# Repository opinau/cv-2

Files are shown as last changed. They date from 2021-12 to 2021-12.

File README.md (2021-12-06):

# OPINAU-FILLER-CV-2

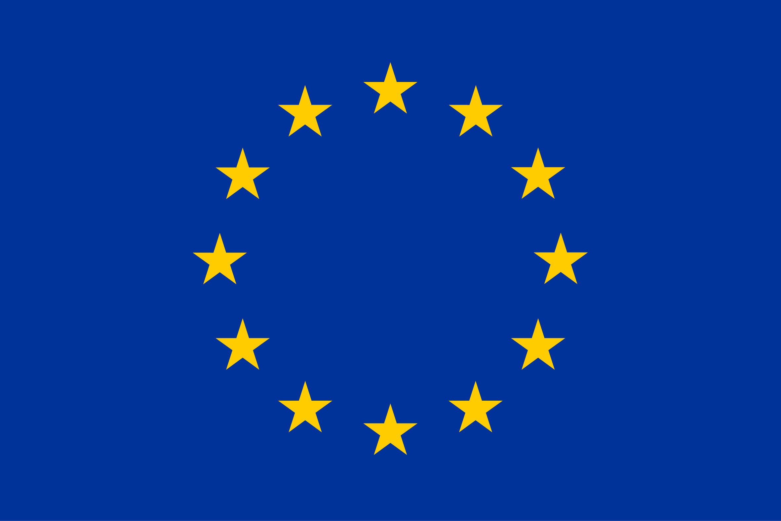
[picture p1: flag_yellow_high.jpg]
EU


Europska unija

Zajedno do fondova EU

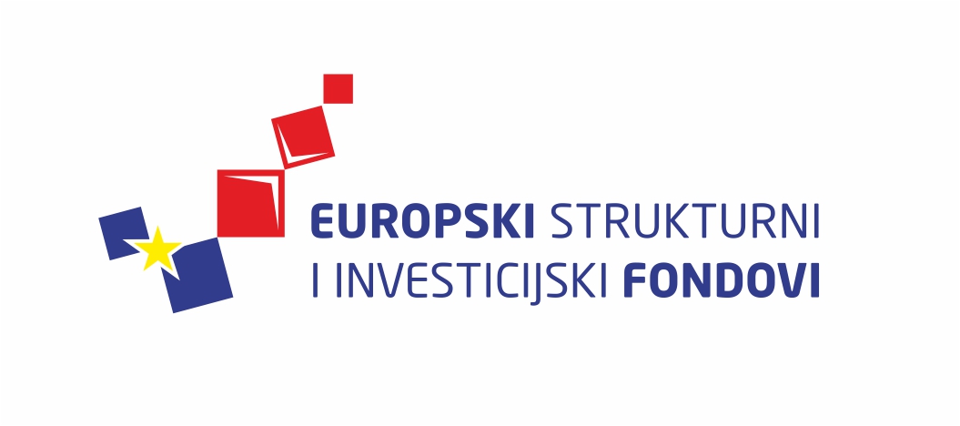
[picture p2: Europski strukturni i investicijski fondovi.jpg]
ESIF (https://strukturnifondovi.hr/)


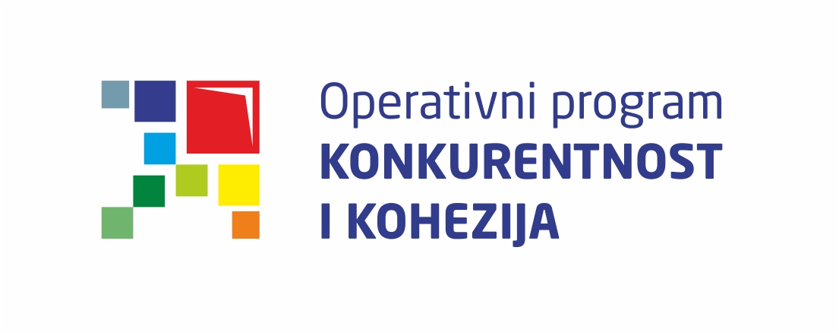
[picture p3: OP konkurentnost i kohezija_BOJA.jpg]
OPKK


Projekt je sufinancirala Europska unija iz Europskog fonda za regionalni razvoj

[**Inovacijski vaučeri za MSP-ove**](https://efondovi.mrrfeu.hr/MISCms/Pozivi/Poziv?id=cfc4e79b-68c5-4ce8-a481-04ee5d76dda2)

Operativni program: **Konkurentnost i Kohezija 2014. - 2020.**

Naziv projekta: **OPINAU-FILLER-CV-2**

OPINAU-FILLER-CV-2 projekt odnosi se na razvoj sklopovlja i popratne programske podrške (unutar Python/C++/ROS okruženja) za prototip sustava za beskontaktno mjerenje razine tekućine u boci prilikom punjenja u open-source punionici piva temeljen na principima računalnog vida sa mogućim odstupanjima od maksimalno 10%.

Partneri na projektu: [**Open Book d.o.o.**](https://www.openbook.hr/) i [**Fakultet elektrotehnike, strojarstva i brodogradnje Sveučilišta u Splitu**](https://www.fesb.unist.hr/)

Ukupna vrijednost projekta: **72.000,00 HRK**

Iznos koji sufinancira EU: **54.000,00 HRK**

Razdoblje provedbe projekta: **09.08.2021. - 03.12.2021.**

Kontakt osoba: **Igor Cota**

---
Repozitorij se sastoji od dva modula:
1. OpenMV modul
2. RaspberryPi modul
---
Prije korištenja pročitajte [dokumentaciju](report/openBookIzvjestaj_ver_4.pdf).

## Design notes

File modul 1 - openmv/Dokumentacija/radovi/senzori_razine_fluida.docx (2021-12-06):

Istraživanje tipova senzora razine fluida

Klasika su Liquid Level Pressure Transmitteri, koji se samo urone u spremnik, to ne igra

Slična stvar je sa ultrazvučnim senzorima i radarskim senzorima, isto ne igraju

Ima jeladn lipi pregled senzora na

https://cecas.clemson.edu/cvel/auto/sensors/fluid-level.html

odnosno

http://www.leveldevilsensors.com/main/electronic-sensors-inc-esi-level-devil-american-made-tank-monitors-and-tank-monitoring-systems/tabk-sensor/

A sada opticki:

Ima na tržištu binarnih senzora razine fluida (zamjena za level switch tj float switch)

https://sstsensing.com/how-our-optical-liquid-level-sensors-work/

Ovoga dosta navode kao optički level nešto..

A sad ide ekipa sa laserima

https://www.lasertech.com/TruSense-S300-Laser-Sensor-Series.aspx

Ovo je ili TOF ili phase whift senzor prilagođen fluidima (ima dodatno raspršenje zrake), relativno visoke razine

Sto se tice cv sustava, tu nalazim vise znanstvenih radova nego pravih komercijalnih sustava

Par linkova:

https://plastrading.com/2017/08/21/how-to-overcome-the-most-common-fill-level-faults-in-full-bottle-containers/

https://heuft.com/en/product/beverage/full-containers/full-container-check-heuft-prime

pitanje je radi li ovo dok se boca puni ili nakon punjenja u liniji?

Koliko se piva pjeni kada se puni?

Ovi imaju nekoliko razlicith sustava za mirenje razina napunjenosti..

Eksplicitno kazu: Not suitable for bottles labelled at the fill level and swing top bottles with a fill level at the bracket area.

https://www.miho.de/en/products/filler-monitoring/filler-monitor-miho-fm-2/

neki fill ic senzor, izgleda dosta jednostavan

http://www.taptone.com/products/fill-level-sensors/fill_ir

ovaj sickov senzor izgleda dosta zanimljiv:

the level is best read from the liquid in the neck of the bottle.

They are mounted on the level probe directly to facilitate optimum detection.

https://www.sick.com/us/en/primary-packaging/filler/measuring-the-level-of-the-bottle/c/p514290

stranica na njemackom, dosta slica ideji o kojoj smo pricali vezano uz laser liniju (planarno) ANWENDUNGEN DER OPTISCHE FÜLLSTANDSKONTROLLE

https://www.bbull.com/binternet/deutsch/sites_d/pro_details_d/fuellstandskontrolle_d/fuellstandskontrolle_d.htm

neki clanak vezano uz koriostenje kamera (cmos / ccd senzor)

https://graphene.limited/deep-dive-into-technology-2/full-container-inspection/fill-level-inspection/optic-with-camera-2/index.html

zanimljivo, ali zahtjeva da nema labelu i da je skorz tranparentan..

https://graphene.limited/deep-dive-into-technology-2/full-container-inspection/fill-level-inspection/laser-fill-level-inspection-2.html

Ukratko, možemo ici u 2 smjera,

- Kamera i neka trigonometrijska shema (tu svatsa moze smetat snimanju, ne virujen da ce imat dobar response time, kakvih 5-6 ocitanja po s)
- Optički ic senzor koji se montira na tip punilice, ograničen u mjerenu razine ali iznimno brz i jednostavan. Moze se ocekivat i preko 100 ocitanja po s.

Ima nekoliko radova koji se baziraju na cisto mv sustavima,openmv + phyton + edge detetction (radove sam skinio)

Triba provjerit kako se ponasa laser line na boci

Lase point lasnisran vertikalno kroz bocu

Kako se vidi zapjenjeni dio

Kamera + ic Led, 'c filter za kameru, tekucine u ic spektru se dosta reflektiraju..

Neke od ideja…

Nekakvi pocetni plan opreme:

RPI 4GB

Kamera no ic cut + ic pass filter

Opencv kamere sa ddr ram, mozda i dodatna noic cut kamera

Proxyimity senzori

Laseri mali + fotodiode

Laser tocka

Laser linija

Difuzerski materijali..

O ovme jos triba raspravit

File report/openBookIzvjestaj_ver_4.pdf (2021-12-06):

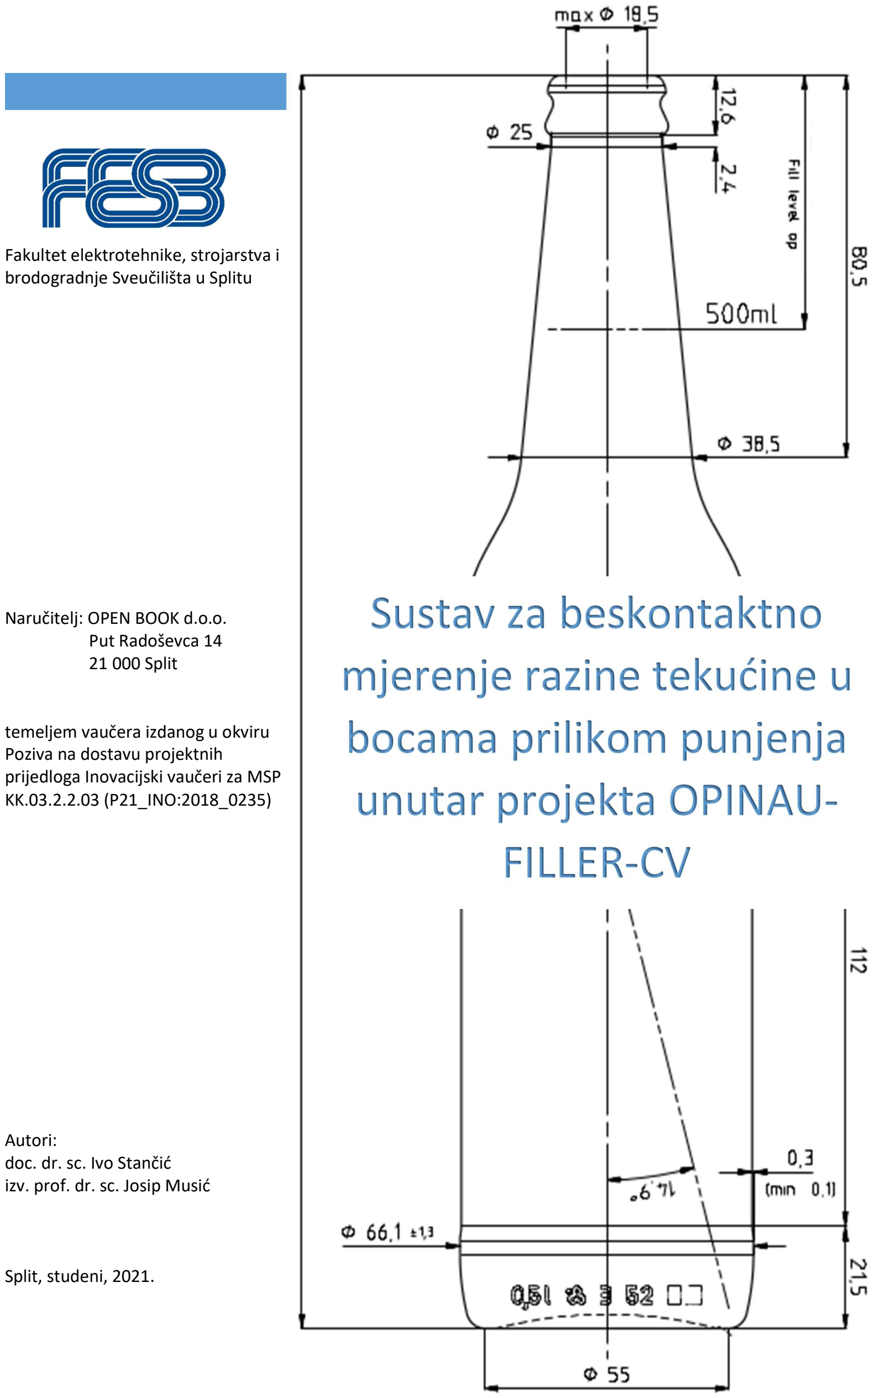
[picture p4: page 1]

1

OPINAU-FILLER-CV

Fakultet elektrotehnike, strojarstva i brodogradnje Sveučilišta u Splitu

Naručitelj: OPEN BOOK d.o.o.
Put Radoševca 14
21 000 Split

temeljem vaučera izdanog u okviru Poziva na dostavu projektnih prijedloga Inovacijski vaučeri za MSP KK.03.2.2.03 (P21_INO:2018_0235)

Autori:
doc. dr. sc. Ivo Stančić
izv. prof. dr. sc. Josip Musić

Split, studeni, 2021.

# Sustav za beskontaktno mjerenje razine tekućine u bocama prilikom punjenja unutar projekta OPINAU-FILLER-CV

## SADRŽAJ

3

## 1. MOTIVACIJA I CILJ

Naručitelj sustava, tvrtka OPEN BOOK d.o.o., je u procesu izrade open-source (sklopovski i programski) tipa punionice za male pivovare odnosno tzv. craft piva. Glavna odlika takvih pivovara odnosno piva je mala serija proizvodnje odnosno izrada od strane pojedinaca (entuzijasta) i manjih poduzeća. Stoga je jedna od glavnih odlika koje razvijeni sustav treba imati cjenovna pristupačnost kao i jednostavna dostupnost svih komponenti od kojih se sustav sastoji, pri čemu sustav ne mora biti u mogućnosti obraditi veliki broj boca kao velike pivovare. Dodatno, potrebno je da je sustav lako za održavati te zamijeniti neispravne komponente, pa čak i da vlasnik/korisnik može intervenirati u programski kod i/ili dodati dodatno sklopovlje (npr. senzoriku). Tragom navedenoga tvrtka OPEN BOOK je izradila prototip punionice (Slika 1) koja sa sastoji od pokretne trake, dijela za lijepljenje naljepnica na boce, punilice pivom i čepilice, a dijelovi za koje su dostupni kao STL datoteke za 3D printanje, odnosno ključne elektroničke komponente putem platformi za trgovinu kao što su e-Bay odnosno AliExpress.

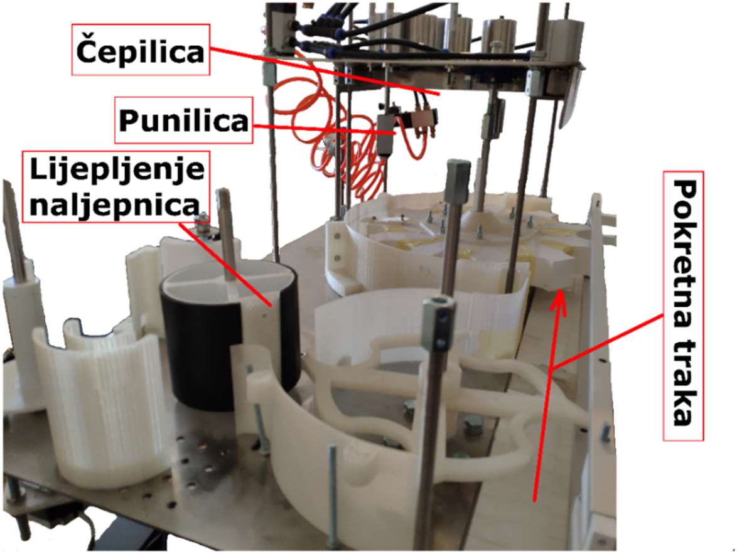
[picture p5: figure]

Slika 1 – Radni prototip OPINAU-FILLER sa naznačenim osnovnim dijelovima (strelica prikazuje smjer kretanja boce) – starija verzija prototpia

Glavni pokretači (Nema 23 bipolarni koračajni motor¹
) prototipa punionice su
dizajnirani i integrirani u sustav, kao i senzorika za praćenje njihovoga rada i trenutno stanja (položaja) boca unutar sustava. Međutim, dio kojemu nedostaje senzorika a kako bi se mogla zatvoriti povratna upravljačka veza je sama punilica. Naime sustav u trenutnoj konfiguraciji ne posjeduje informaciju o stvarnom stanju razine piva tijekom punjenja, već ventil za punjenje drži otvorenim unaprijed određeno vrijeme. Prilikom punjenja, a kako bi se smanjilo pjenjenje, boca sa pod pritiskom prvo napuni ugljičnim dioksidom (korak pripreme) a zatim kreće samo punjenje pivom. Budući da ugljični dioksid dolazi iz spremnika pod pritiskom, a čiji pritisak

1 https://www.omc-stepperonline.com/nema-23-bipolar-1-8deg-1-26nm-178-4oz-in-2-8a-2-5v-57x57x56mm-4-wires.html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

4

opada kako se boca dioksida prazni, to se pritisak u boci piva prilikom punjenja također mijenja. Ovo pak za posljedicu može imati da vrijeme punjenja (u otvorenoj petlji) koje se postavi kada je boca dioksida puna više nije dovoljno dobro kako se boca prazni. Iako su tolerancije prilikom punjenja relativno velike (10% prema zahtjevu naručitelja), poželjno je da punjenje bude što bliže deklariranoj vrijednosti, te da se u slučaju neželjenih efekata (prepunjena boce, preveliko pjenjenje i slično) proces može ili zaustaviti ili obavijestiti operatera o nastaloj grešci.
Prije početka razvoja traženog modula za detekciju razine tekućine u boci prilikom punjenja, napravljen je kratki pregled dostupnih znanstvenih i komercijalnih sustava. Predstavljanje potpunog pregleda izlazi izvan okvira ove studije, ali moguće je konstatirati da se dostupni senzori mogu grubo podijeliti u dvije skupine: kontaktni i beskontaktni. Daljnja podjela je moguća s obzirom na princip rada²
: mehanički, magnetski, elektrostatički, ultrazvučni, optički i slično. Moguća je i kombinacija više senzorskih modaliteta u jednu
jedinicu | kao | npr. | u | komercijalnom | sustavu | Heuft | Prime
(https://heuft.com/en/product/beverage/full-containers/full-container-check-heuft-prime). Potrebno je također primijetiti da se razina tekućine može mjeriti na dva mjesta: prilikom samog punjenja (što je izazovniji problem zbog prisustva mlaza za punjenje i eventualnih dodatnih dijelova punilice a u svrhu uključenja u regulacijsku petlju – to je problem kojim se bavi ova studija) ili nakon punjenja samo za kontrolu razine (ova studija samo predlaže rješenje za ovaj slučaj ali ga detaljnije ne razmatra i testira)..
Zbog sanitarnih razloga i zahtijeva koje oni nameću poželjno je da senzor za mjerenje razine tekućine u boci prilikom punjenja bude beskontaktan. Stoga su metode strojnog vida prepoznate kao dobri kandidati koji osim što zadovoljavaju zdravstvene kriterije (beskontaktnost) se vrlo dobro uklapaju u paradigmu otvorenog pristupa istaknutu u uvodu (npr. lako ih je mijenjati i nadograditi). Pri tome su postavljeni slijedeći konstrukcijski zahtjevi: 1.) potrebno je koristiti lako dobavljive i cjenovno pristupačne komponente, 2.) sklopovlje mora po svojim dimenzijama mora biti prikladno za integraciju u razvijeni prototip punionice, 3.) sustav treba raditi u realnom vremenu s latencijom ne većom od 200 ms što odgovara brizni ne manjom od 5 sličica u sekundi, 4.) programska podrška treba na svome izlazu davati kontinuiranu vrijednost (trenutno stanje razine) kao i diskretnu vrijednost (da li je dosegnuta željena razina punjenja), 5.) izlaz iz programske podrške treba biti pogodan za kasnije spajanje s ROS-om (eng. Robotic Operating System³
), 6.) sustav treba biti otporan na promjene osvjetljenja u radnoj okolini, i 7.) sustav treba biti lak za rukovanje (posebno kalibracijska faza – ukoliko je potrebna).
Tijekom ove studije inicijalno je testirano više pristupa upotrebom različitih modaliteta (sklopovlja) mjerenja, ali su naposlijetku dva odabrana kao obećavajuća te su stoga detaljnije predstavljena u ovome Izvještaju (primjer jednoga sustava je na Slici 2), i za njih su razvijeni prototipovi modula. Navedeni su osnovni sastavni dijelovi kako bi se mogli jednostavno reproducirati (open-source filozofija), kao i cjeloviti kod koji se planira učiniti javno dostupnim

2 http://www.leveldevilsensors.com/main/electronic-sensors-inc-esi-level-devil-american-made-tank-monitors-and-tank-monitoring-systems/tabk-sensor/

### 3 https://www.ros.org/

5

(pod odgovarajućim licencama) putem GitHub platforme⁴
(opet, u skladu s open-source filozofijom). Potrebno je napomenuti da su svi moduli detaljno testirani u laboratorijskim uvjetima sa ciljanim tipovima boca piva (kojima su i prilagođeni) dok u praktičnoj eksploataciji se mogu javiti neke dodatne neplanirane situacije koje će se trebati naknadno adresirati. Kako bi se minimizirao ovaj efekt jedan od razvijenih prototipova (Modula 1) je u dogovoru s naručiteljem i kratko testiran u relni(ji)m uvjetima prave punionice (ali ne i prilikom stvarnoga punjenja piva). Također, razvoj sustava je prilagođen određenom tipu i udaljenosti pivske boce, ali je kroz (jednostavni) postupak kalibracije (putem ugrađenog mini LCD ekrana) ostavljena mogućnost prilagodbe istih, te posljedične programske prilagodbe odgovarajućih programskih/mjernih parametara. Na taj način je modul postao fleksibilniji i moguće ga je koristiti u više različitih konfiguracija i više različitih namjena. Svi kodovi su pisani u Python programskom jeziku, tako da i korisnici sa manje iskustva mogu po želji prilagođavati funkcionalnost modula.
Naposljetku je potrebno još jednom istaknuti i činjenicu da je tijekom razvoja predloženih sustava testirano više različitih kamera, senzora i mikrokontrolera (u vidu brzine i pouzdanosti rada kao i jednostavnosti upotrebe i nadogradnje), te su predstavljene komponente one koju su naposljetku odabrane a koje ispunjavaju tražene kriterije naručitelja. Za potrebe modula je dizajnirana i izrađena posebna tiskana pločica kao i dizajnirano više mehaničkih dijelova od aluminijskih profila.

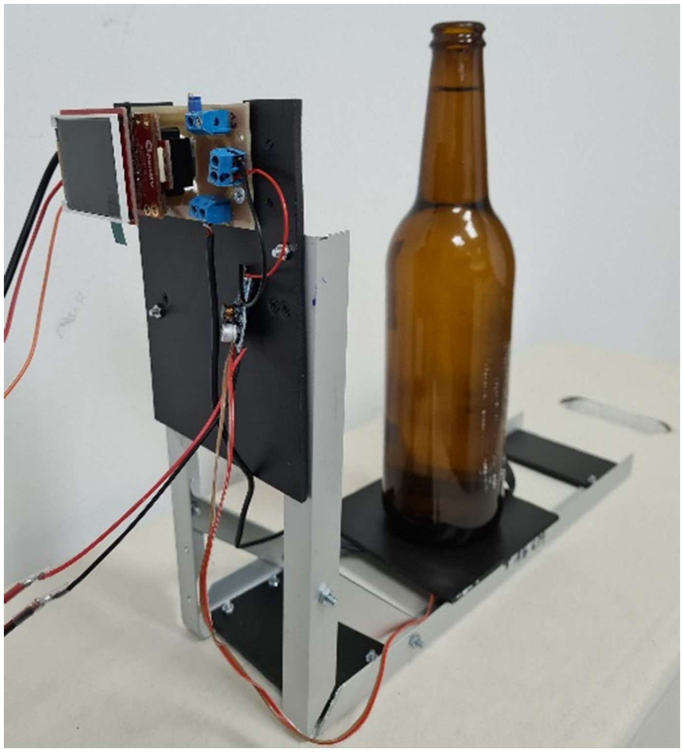
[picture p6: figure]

Slika 2 – Primjer jednog modula razvijenog prilikom izrade studije

Prilikom razvoja sustava za praćenje je testirano nekoliko kombinacija najpopularnijih kamera i mikro kontrolera koji se koriste u MV-u (eng. Machine Vision). Odluka da se u konačnici ne koristi niti jedan specifični mikrokontroler (ugradbeno računalo) već stand-alone kamera je bilo motivirano činjenicom da sustav bude prijenosan i da se može jednostavnije integrirati u postojeću upravljačku logiku. Dodatno, ovakva odluka doprinosi jednostavnosti izgradnje i održavanja sustava, Zbog potpunosti razmatra neki od predloženih sustava su testirani i sa Raspberry Pi 4B+ ugradbenim računalom. Jednostavna usporedba nazivnih

### 4 https://github.com/

6

vrijednosti je na strani RPi platforme budući da testovi pokazuju znatnu razliku između OpenMV H7 plus kamere (ARM Cortex-M7) koja radi na taktu 480 MHz i Raspberry Pi 4B (ARM.Cortex A72) na taktu 1.5GHz (Core Mark Performance 2400 u odnosu na 48,626)⁵ 6 .
Međutim OpenMV H7 plus je dizajniran za primjene strojnog vida, pa kao takav ima neke prednosti kao što su: brza sabirnica (3.84 GB/s), manja potrošnja energije, manje dimenzije i integrirana kamera i mikrokontroler, izravno programiranje i slično. Upravo iz navedenih razloga je isti bio prvi izbor u razvoju predloženog sustava.
Primjer svog testiranog sklopovlje je dan u Tablici 1 kako bi čitatelj dobio bolji osjećaj za performanse drugog sklopovlja, te stoga nisu namijenjeni za direktnu usporedbu s konačnim sustavom. Također, smatramo da bi uključivanje potpunih preliminarnih rezultata u ovu studiju nepotrebno pomaklo fokus sa predloženog sustava i njegovih karakteristika, te stoga oni i nisu uključeni (već samo njihov sažetak kako slijedi).
Inicijalna ideja sustava za detekciju razine tekućine u boci se temeljila na primjeni linijskog lasera i detekcija efekta refrakcije/loma svjetlosti (primjer detekcije na Slici 3). Međutim, testiranja su pokazala da zbog specifičnosti upotrjebljenih boca (nesavršenog oblika) i radnog okruženja željeni efekti nisu dovoljno izraženi i stabilni da bi bili primjenjivi, te se stoga odustalo od navedene ideje. Npr. primijetilo se da jako mali pomaci boce (tek nekoliko mm) mogu rezultirati pomakom zrake, što se može prepoznati kao lažno napunjenost boce.

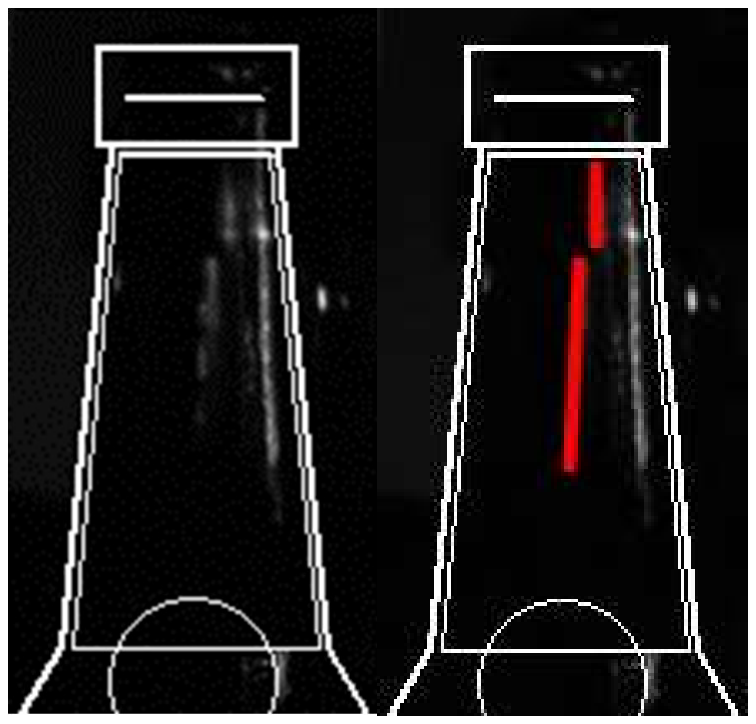
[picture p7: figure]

Slika 3 – Primjer loma laserske linije kod detekcije razine tekućine
Na slične probleme se naišlo kod pokušaja primjene IR senzora udaljenosti: zbog boce i zaštita koje ima nije bilo moguće dobiti smisleno i stabilno rješenje. Stoga se pristupilo pronalaženju alternativnih principa rada, a koji će biti predstavljeni u slijedećem poglavlju. Dodatna ideja koja se testirala ali koja nije pokazala zadovoljavajuće rezultate (pa se stoga odustalo od njezina daljnjeg razvoja i testiranja) se temeljila na svojstvu apsorpcija svjetlosti boce i tekućine. Kako se radi o jako maloj količine relativno prozirne tekućine, smanjenje intenziteta svjetlosti zbog apsorpcije u tekućini je minimalno i u ovom slučaju nije davalo dovoljno kvalitetne rezultate (primjer na Slici 4). Na slici je prikazan idealan slučaj kada se linija jako dobro može razaznati ali u realnim situacijama zbog male razlike intenziteta

### 5 https://www.eembc.org/viewer/?benchmark_seq=13417 6 https://openmv.io/products/openmv-cam-h7-plus

7

„linije“ tekućine i ostatka boce razlika je minimalna i podložna utjecaju smetni (npr. okolnog osvjetljenja).

Slika 4 – Primjer detekcije razine tekućine temeljem svojstva

Tablica 1 – Usporedba osnovnih karakteristika testiranog sklopovlja tijekom studije
Sklopovlje | Rezolucija/ udaljenost | Podržane platforme | Ostale (bitne) karakteristike
Arducam OV9281 1MP kamera | 1280x800 (1MP) | Raspberry Pi 4, Pi 3/3B+/3A+, CM3/3+, Pi Zero, Arduino | Monokromatski globalni shutter. Senzor ¼ incha. Ugrađen 650nm IR cut-off filter (samo vidljiva svjetlost). Maksimalna brzina 120 fps. Veličina 40x40 mm.
Arducam Stereoscopic Camera kit OV9281 | 1280x800 (1MP) | Raspberry Pi 3B/3B+/4B and Jetson Nano/NX | Dvije OV9281 !MP kamere sa sinkroniziranim globalnim shutterom. RAW8/RAW10/RAW12 izlazni format. Bez IR filtera (osjetljivo na IR). MIPI serijsko sučelje. Distorzija <1%. FOV 70 stupnjeva (H).
OpenMV H7 plus | 592x1944 (5MP) | Neovisno o računalnoj platformi (stand alone ili serijska veza sa drugim uređajem) | STM32H743II ARM Cortex M7 procesor sa 480 MHz i 32MB SDRAM + 1MB RAM + 32 MB vanjskog flasha + 2 MB unutarnjeg flasha.OV5640 optički senzor. Može vrtiti custom algoritme na svome procesoru s brzinama do 50 fps.
Pololu 38kHz IR senzor blizine | 60 cm | Analogno sučelje – sve ploče koje imaju pinove koji mogu čitati analogne signale | Baziran na Vishay’s TSSP77038 modulacijskim IR prijemnicima. Digitalni senzor sa prilagodljivijom (trimmer) referentonm udaljenošću.
Zeleni laser snage 25 mW | 3 m (tipično) | NA | Prilagodljivi fokus. Kut 60 stupnjeva. Akrilni kolimator. Napajanje 12 – 25 VDC. Valna duljina 515-520 nm. Klasa 1/2.

8

## 2. MODUL ZA DETEKCIJU RAZINE TEKUĆINE PRILIKOM PUNJENJA – Modul 1

Prototip (laboratorijskog) sustava za detekciju razine tekućine u boci je prikazan na Slici 5 (s označenim glavnim dijelovima), a njegovo planirano mjesto na proizvodnoj liniji (Slika 1) je u punilici. Potrebno je primijetiti da prototip sadrži i neke konstrukcijske i nosive dijelove (aluminijski profili) koji neće nužno biti dio prototipa na proizvodnoj liniji budući da će se sustav postavljati na već postojeću konstrukciju na za to prikladan način. Pri tome će osim dodavanja komponenti, zbog prirode razvijenog sustava biti potrebno i prilagoditi postojeće komponente (podloga na kojoj se boca nalazi) a kako bi se mogle ugraditi ključne komponente (LED). Slika 5 sadrži detaljan uvid u sve komponente laboratorijskog sustava.

Slika 5 – Prototip modula za detekciju razine tekućine u boci s označenim osnovnim dijelovima iz nekoliko kuta gledanja

9

Iz donjeg dijela Slike 5 je vidljivo da da predloženi sustav ne detektira razinu tekućine na cijeloj visini boce, već samo na završnom dijelu (vrhu) gdje je to kod punjenja i najbitnije. Važna pretpostavka je da u trenutku punjenja boca još uvijek nema nikakvu naljepnicu na svome grlu. Naime na ovaj način, fokusiranjem područja, se postigla bolja točnost i pouzdanost mjerenja koja kod širega kuta ne bi bila moguća. Primjer vidnog polja OpenMV H7 plus kamere sa naznačenom minimalnom (donja linija) i maksimalnom (gornja linija) razinom tekućine za mjerenje dan je na Slici 6 (udaljenost kamere od boce je bila približno 16 cm). U konkretnom primjeru za naznačene linije radilo se o napunjenosti boce između 470 i 520 ml (pri čemu su očekivane manje varijacije zbog tolerancija kod proizvodnje boca).

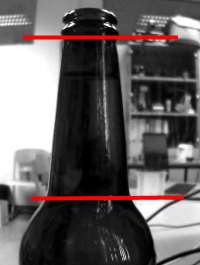
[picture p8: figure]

Slika 6 – Boca iz vidnog polja kamere s oznakama minimalne i maksimalne razine tekućine koje može izmjeriti

Metode mjerenja razine fluida u transparentnoj ili polu-transparentnoj posudi (boci) u predloženom sustavu se temelje na ključnom svojstvu materijala: reflektivnosti. Pretpostavka je da jaki izvor svjetlosti osvjetljava bocu (od dolje) u jako kratkim vremenskim intervalima (nekoliko ms), i svjetlost se širi od dna boce prema vrhu, pri čemu se rasprostranjuje cijelom bocom (ovo je iznimno važno, ne radi se o usmjerenom svjetlosti već o izvoru svjetlosti sa velikim kutom djelovanja). Svjetlost se reflektira kada prelazi između različitih medija (Snellusov zakon⁷
), što uključuje prelazak iz fluida na staklo ali i sa fluida na zrak. Dio svjetlosti koji se reflektira prilikom prelaska iz fluida u zrak upada u leću kamera, i kamera ga vidi kao područje jačeg intenziteta svjetlosti. Kamera snima dvije slike u kratkim vremenskim razmacima, pri čemu je prva slika osvjetljena snažnim LED izvorom, dok je druga slika u normalnim uvjetima (bez dodatnog izvora svjetlosti). Jednostavnom operacijom oduzimanja se mogu izdvojit razlike među tim slikama. Ovaj efekt i njegovi rezultati su prikazani na Slici 7.

### 7 https://www.enciklopedija.hr/natuknica.aspx?ID=52225

10

Slika 7 – Operacije nad slikama snimljenim u dva uzastopna trenutka (sa i bez LED osvjetljenja)
Osim refleksije od prelaska svjetlosti iz fluida u zrak, na slici 7 (desno) se može detektirati i refleksija koja je posljedica prelaska svjetlosti iz fluid u staklo na samom početku grla (donja oznaka). Navedemo je detaljnije označeno i prikazano na Slici 8.

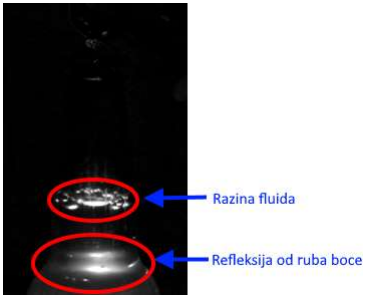
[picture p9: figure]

Slika 8 – Refleksije zbog efekata na boci i razine tekućine u boci

Premda je ova refleksija manje-više ujednačenog oblika u istoj boci, zbog različitih oblika boca (velikih tolerancija tokom izrade) mogu se promotriti različiti oblici refleksije. Zbog ovoga je dio početka grla boce jednostavno izbačen iz analize, te se promatraju refleksije samo na ostatku grla boce predefinirane veličine, a što je predstavljeno maskom vidljivom na Slici 9.

11

Slika 9 – Maska za definiranje mjernog područja i minimizaciju utjecaja neželjenih artefakata

Ovdje je potrebno istaknuti da se prilikom razvoja sustava testiralo više različitih izvora svjetlosti (primjeri rezultata su prikazani na Slici 10), ali se najboljim izvorom pokazala obična bijela LED snage minimalno 1W (koja se inače koristi za automobilske farove – smatramo da odabir navedene komponente ima značajnu prednost što već sadrži regulator koji se brine za ispravno napajanje naponom i strujom LED-a). Isto tako testirano je i više leća sa filterima: IC cut, IC pass i bez ikakvog IC filtera na leći (Slika 11).

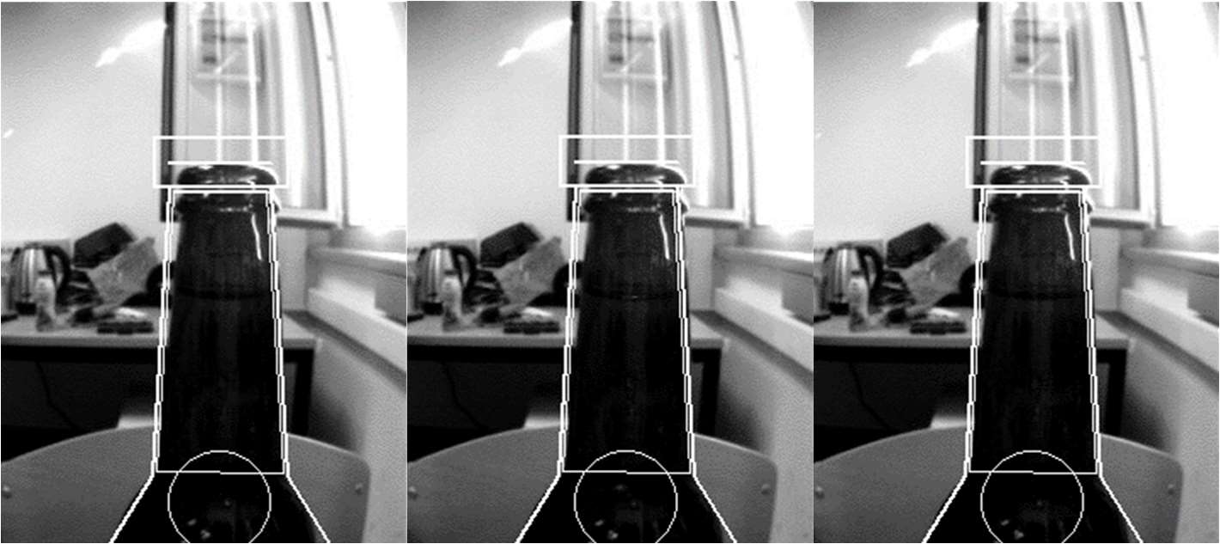
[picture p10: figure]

IR 1W | crveni LED 10mW | UV 395nm

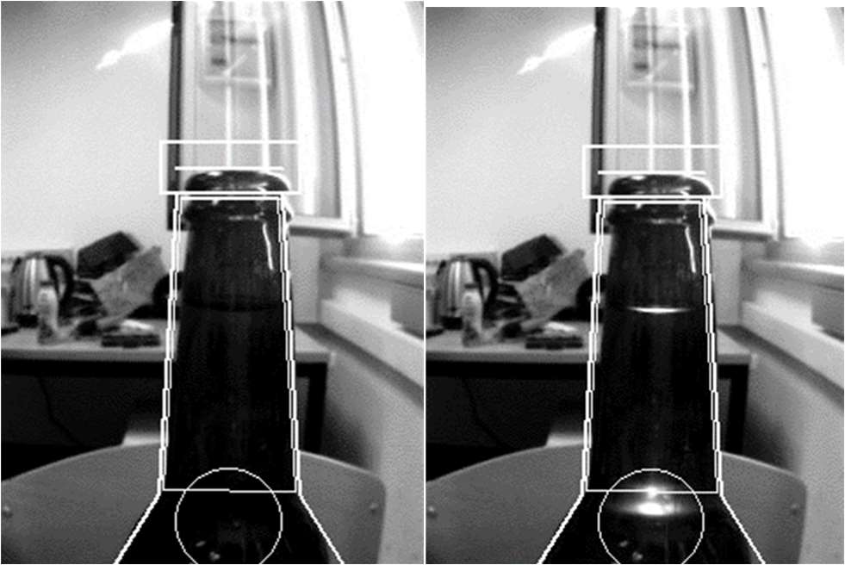
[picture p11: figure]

uv 420nm | bijeli LED 1W

Slika 10 – Primjeri testiranja različitih vrsta izvora svjetlosti ispod pivske boce

12

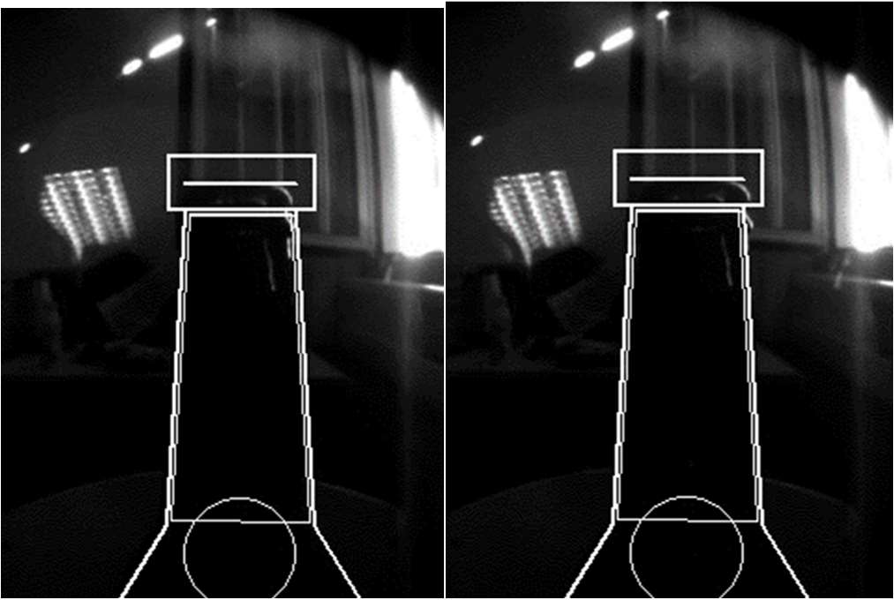
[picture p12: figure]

IR pass, izgašeno | IR pass, IR 1W

Slika 11 – Primjeri testiranja različitih vrsta filtera

Tijekom testiranja sustava zamijećeno je da oblik refleksije koji kamera može zabilježiti se može svrstati u 3 različite kategorije, kao što je i prikazano na Slici 12, a što se onda može dodatno iskoristiti za klasifikaciju događaja u boci/punilici (pri budućem razvoju).

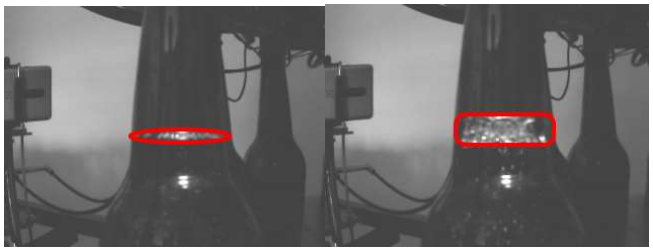
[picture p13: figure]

Tip 1 | Tip 2

Tip 3

Slika 12 – Primjeri različitih jedinstvenih uzoraka zamijećenih tijekom testiranja sustava

13

Različiti su oblici primijećeni kada fluid miruje, i kada se boca puni fluidom, pa je i sam algoritam sustava strojnog vida prilagođen da može detektirati bilo koji od potencijalnih oblike. Pa tako Tip 1 na Slici 12 predstavlja mirnu razinu tekućine bez (ili s vrlo malo) pjene, dok Tip 2 predstavlja razinu koja se još nije ustalila budući da ima značajan udio pjene. Tip 3 je karakterističan za sam proces punjenja, kada tekućina koja dolazi iz punilice upada u tekućinu u bocu ispod razine trenutnog punjenja a što je vidljivo kao niz manjih površina ispod najviše detektirane razine (koja predstavlja razinu tekućine).
Konačna inačica sustava implementirana unutar mikrokontrolera OpenMV H7 plus kamere doseže brzinu rada od oko 7 parova sličica u sekundi (fps; jedna potpuna obrada traje oko 150 ms), što bi trebalo biti dovoljno za upravljanje punjenja boce koje traje predvidivo 10-30 s. Uzevši u obzir navedeno vrijeme punjenja (30 s), kao i ciljani volumen boce (500 ml) proizlazi prosječna brzina punjenja od oko 16.5 ml/s. Ukoliko se uzme brzina snimanja od 7 fps-a, jednostavnim računom se dobije da je teoretska rezolucija sustava (tj. minimalna razlika promjene volumena između dva snimljena okvira) oko 2.3 ml.
Premda je sustav detekcije razine na kojoj se nalazi „refleksija“ (tj. razina tekućine) iznimno precizan, zbog nemogućnosti točnog razlikovanja radi li se samo o fluidu ili postojanju male količine pjene, ovaj sustav je točan u razini ~ 2-5 ml. Radi usporedbe veličina na slici i u stvarnosti napominjemo da na sredini grla boce razlika od 20 piksela odgovara razlici volumne fluida od oko 5 ml. Pri tome sustav radi na rezoluciji od 320 x 240 piksela, dok je radno područje sustava (maska sa slike 9) visine oko 150 piksela, i odgovara razini fluida u prosječnoj boci od 470 do 520 ml.
Tijekom razvoja sustava isti princip rada testiran je s drugačijim sklopovljem odnosno sa ArduCam OV9281 1Mpix (NoIR) kamerom u kombinaciji s Raspberry P 4 Model B (Slika 13). Ovakva kombinacija se pokazala sposobnom ostvariti znatno veće brzine rada od 20 fps-a, međutim zbog jednostavnosti samog senzora (sustava) za krajnju realizaciju se predlaže pristup sa OpenMV kamerom (koji ima prednost i da prilikom ponovnog paljenja se znatno brže podiže od RPi računala). Izgled mjernog sustava za ovakve postavke je prikazan na Slici 14.

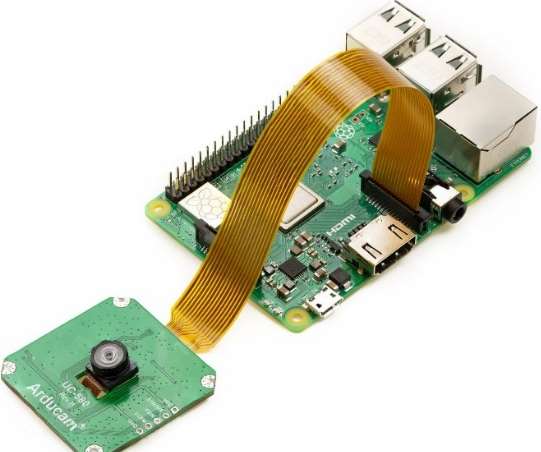
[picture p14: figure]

Slika 13 – Način spajanja Arducam OV9281 1Mpix kamera sa RPi 4B računalom

14

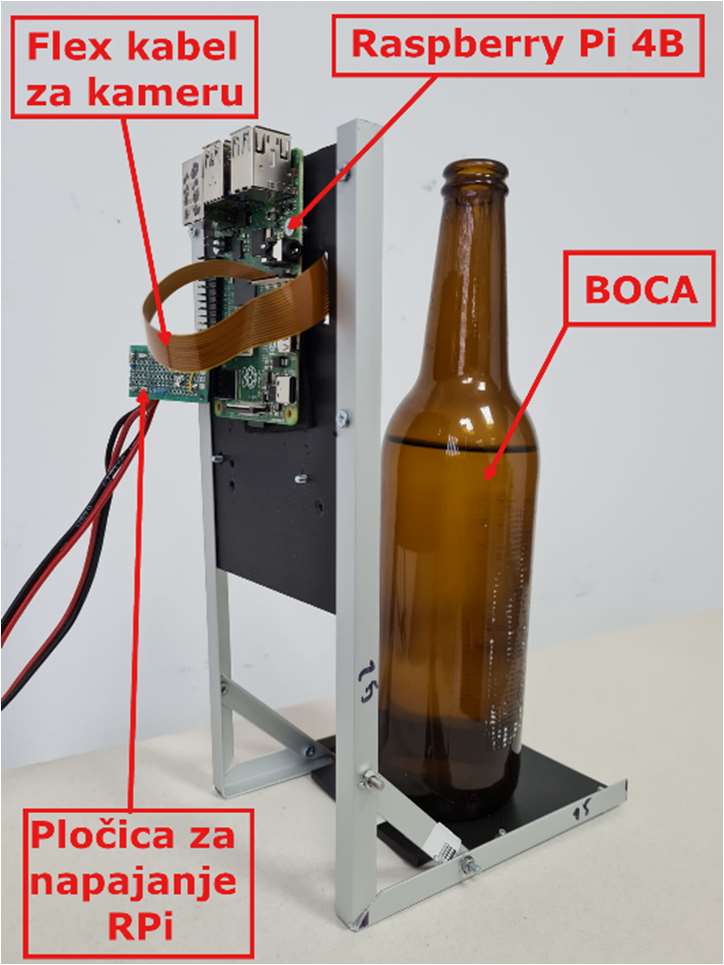
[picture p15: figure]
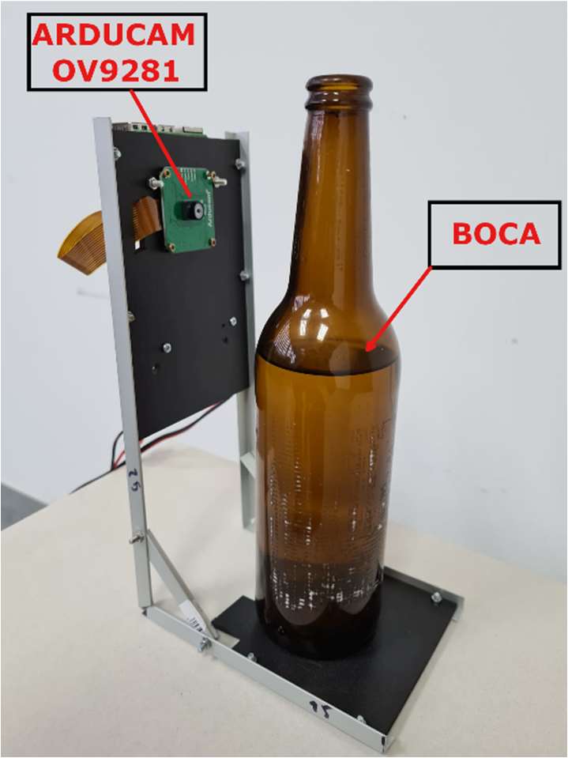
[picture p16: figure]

Slika 14 – Način spajanja Arducam OV9281 1Mpix kamera sa RPi 4B računalom

Pri radu s OpenMV H7 plus kamerom bilo ju je potrebno unutar Python programskog okruženja postaviti na njezinom mikrokontoleru njezine postavke na slijedeći način (a kako bi se ostvarili/reproducirali ovdje prikazani rezultati):

sensor.set_pixformat(sensor.GRAYSCALE) # set camera format to grayscale (color not important in this example)

sensor.set_framesize(sensor.QVGA) # set camera resolution to QVGA 320 x 240

sensor.set_auto_exposure(False, exposure_us=user_exposure_time) # set exposure time, user changable (user_exposure_time variable)

sensor.set_auto_gain(False,gain_db=22) #set camera gain, keep it as this value is optimised for given light source and exposure time

sensor.set_brightness(3) #set camera brightness , range -3 to +3

sensor.set_contrast(3) #set camera contrast , range -3 to +3

Naravno, parametre je moguće naknadno mijenjati s obzirom na tražena svojstva i svojstva okoline gdje se senzor postavlja. Dodatno ključno svojstvo koje se postavlja je:

sensor.set_framebuffers(1)

koji omogućava kameri da snima samo jednu sliku u framebuffer, tako da kamera mikrokontroleru šalje samo najsvježiju sliku na obradu. Što se tiče samog postupka dobivanja

15

razlike slika kada je LED upaljen i ugašen (Slika 7), odnosno tzv. frame differencinga, on se može jednostavno implementirati putem slijedećih naredbi:

pin_LED.value(True) #turn on main LED

time.sleep_ms(5) #sleep for 5ms (allow LED to reach full brightness)

img = sensor.snapshot() #take first image (led is on)
time.sleep_ms(2) | # wait for a few ms
extra_fb.replace(sensor.snapshot()) | #put first image in to
additional frame buffer
pin_LED.value(False) | #turn off main LED
time.sleep_ms(5)

img = sensor.snapshot() #take second image (led is off)
time.sleep_ms(2) | # wait for a few ms
img.difference(extra_fb) #simple frame differencing, first and second image

Važan prvi korak pri instaliranju sustava (koji se radi samo jednom i eventualno dodatno ako dođe to pomicanja nosivih komponenti/dijelova) je kalibracija sustava. Zadatak kalibracije je namjestiti kameru i nosivu konstrukciju na način da se boca prilikom punjenja nalazi u dijelu slike u kojem je očekuje (i s kojim radi i za koji ima masku) a kako bi se grlo boce (odnosno gornji dio boce) moglo pouzdano i točno izdvojiti. Kako bi se olakšao ovaj postupak u uvjetima realne primjene, u sustav je ugrađen mali LCD ekran koji se pali uklanjanjem kratkospojnika sa slike 5. U tome trenutku pali se spomenuti LCD ekran te se na njemu prikazuje slika sa OpenMV H7 plus kamere i template boce koji služi za namještanje (vidljiv na Slici 15).

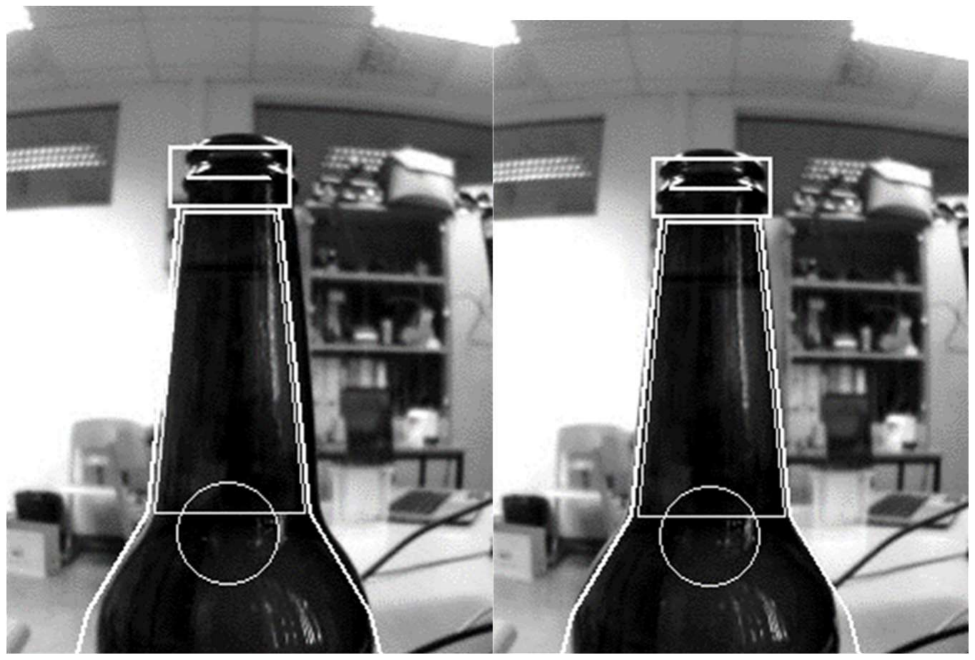
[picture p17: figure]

Slika 15 – Način spajanja Arducam OV9281 1Mpix kamera sa RPi 4B računalom

16

Korisnik zatim treba bilo pomicanjem položaja boce koja se puni (što je teže za očekivati) ili konstrukcije koja nosi kameru, namjestiti bocu da što bolje odgovara templateu (pri čemu je template izrađen za vrstu boce koja se koristi u punionici). Na lijevom dijelu slike 15 se vidi da poklapanje boce i templatea nije idealno (boca je previše desno), dok na desnom dijelu slike poklapanje je idealno. Jednom kada se postigne zadovoljavajuće preklapanje i konstrukcijski dijelovi učvrste u novom položaju, vrati se kratkospojnik koji uzrokuje gašenje ekrana (na njemu je samo logo tvrtke OPEN BOOK d.o.o.). Time je sustav spreman za rad (sa deklariranom točnošću) te LED počinju bljeskat (jednom kada dobiju naredbu za početak sa udaljenog centralnog računala). Ukoliko je potrebno postupak kalibracije je moguće ponoviti skidanjem kratkospojnika.
Paljenje i gašenje LED izvora bijele svjetlosti je ostvareno korištenjem MOSFET-a IRFZ44N. Kako bi se ovaj MOSFET i druge komponente (npr. kratkospojnik) mogli jednostavno integrirati sa OpenMV H7 plus kamerom i njezinom pločicom u programskom okruženju KiCad je izrađena prilagođena tiskana pločica koja je zatim i proizvedena. Izgled pločice unutar KiCad programa je vidljiva na Slici 16.

Slika 16 – Izgled KiCad sučelja sa dizajniranom prilagođenom tiskanom pločicom

U trenutnoj implementaciji razvijeni sustav nije integriran unutra ROS čvora (kao krajnjoj ciljanoj arhitekturi razvijenog sustava), ali je kao generalna priprema (ne samo za ROS već i za druge moguće arhitekture) implementirano izvještavanje o stanju punjenja boce putem standardiziranih poruka i USART komunikacijskog sučelja. U slučaju da se radi o ROS arhitekturi ovakve poruke bi se mogle slati na npr. Arduino Nano mikrokontroler koji bi ih primao i na sebi imao pokrenut ROS čvor koji bi ih zatim objavljivao unutar ROS arhitekture. Slanje preko USART komunikacijskog sučelja na OpenMV H7 plus mikrokontroleru je implementirano sa naredbama (koje se naravno po potrebi mogu mijenjati):

uart = UART(4, 9600) #UART pin 4, 9600 baudrate

uart.write(message+"\n")

17

Objekt message koji se šalje odnosno koji služi za izvještavanje sadrži slijedeća podatkovna polja: message = <a,b,c,d,>
gdje je:
a- Razlika u pikselima od trenutne linije do predefinirane crte maksimalne razine punjenja boce
b- Lokacija na slici gdje se trenutno nalazi linija
c- Visina bloba koji je detektiran (povezano s efektima na Slici 11).

Potrebno je istaknuti da je komunikacija preko USART komunikacijskog sučelja u predloženom sustavi zamišljena kao dvosmjerna. Naime, osim prethodno definiranih izvještajnih poruka, mikrokontroler kamere OpenMV H7 plus se konfiguriran i da može primiti dva znaka:

- T - završava mjerenje, sustav čeka novu naredbu-
- S - starta novo mjerenje, sustav izvještava o stanju.

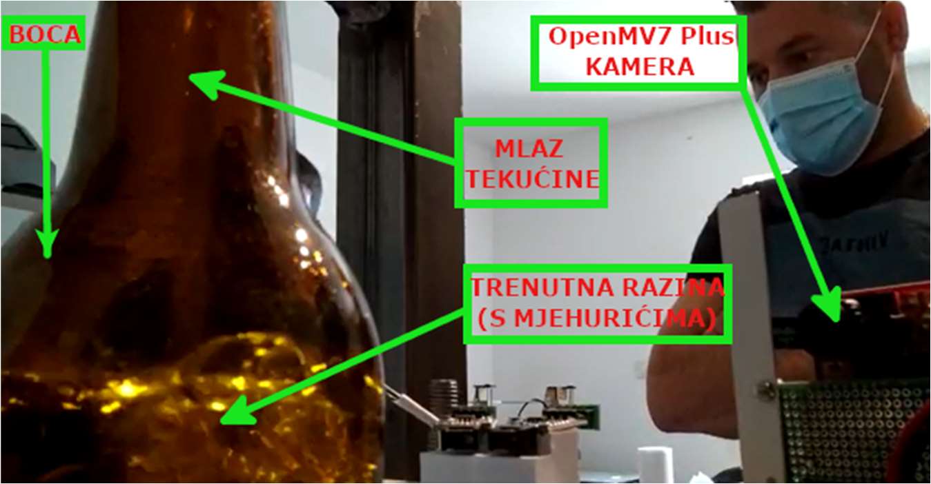
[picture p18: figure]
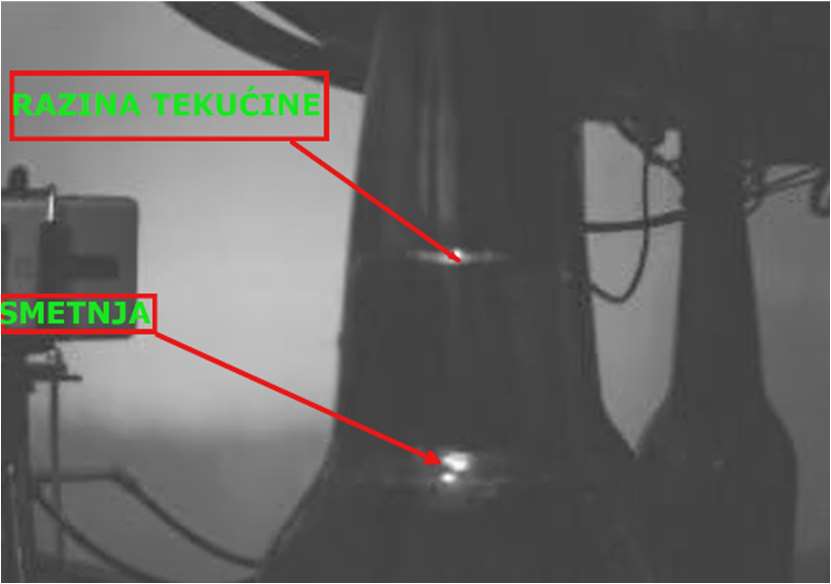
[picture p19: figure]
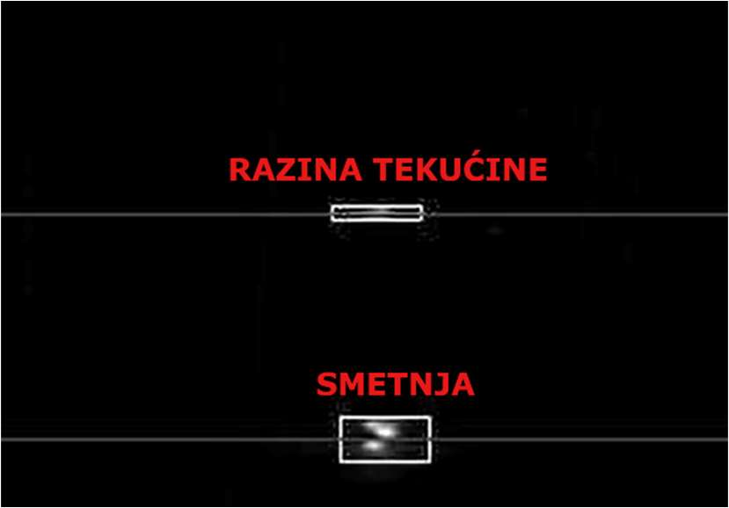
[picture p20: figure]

Slika 17 – Detalji sa testnog mjerenja na samoj punilici (iz perspektive punilice i OpenMV H7 plus kamere)

18

Njihova zamišljena namjena u sustavu je slijedeća. Budući da se (promatrajući samo jednu bocu) proces punjenja sastoji od dovođenja boce u željeni položaj, pripreme za punjenje tekućinom (punjenje plinom), sami proces punjenja, te pomicanje boce dalje u proces proizvodnje nema potrebe da LED i kamera rade cijelo vrijeme (nego samo u koraku punjenja). Stoga kada je sustav spreman za punjenje mikrokontroleru kamere se šalje znak S (iz centralne upravljačke jedinice) za početak mjerenja. Kamera prima taj znak, uključuje LED i počinje slati preko USART-a izvještajne poruke. Kada se dosegne željena razina tekućine u boci, centralni sustav prekida punjenje i šalje znak T mikrokontroleru kamere za prekidom mjerenja. Time kamera gasi LED i prestaje slati izvještajne poruke. Detalji cjelokupne programske implementacije su dostupni u (komentiranom) programskom kodu koji se naručitelju isporučuje u elektronskom obliku uz ovo Izvješće.
Prije same isporuke sustava naručitelju izvršeno je testiranje na samoj punilici (ali ne u stvarnim uvjetima punjenja boce piva budući da je punilica bila u ciklusu održavanja). Detalji testiranja su prikazani na Slici 17. Ukupno ponašanje sustave je bilo u skladu s očekivanjima i bez nepredvidljivih događaja. Na Slici 17 je zanimljivo primijetiti i artefakt smetnje koji je posljedica oblika boce i refleksije svjetla na njemu. Ova smetnja je stoga statična te se kao takva (a i uz pomoć templatea sa Slike 9) može jednostavno eliminirate (izvan mjernog područja je) te ne utječe na samu točnost i pouzdanost mjerenja. Dodatno je zanimljivo primijetiti (na donjoj lijevoj slici) da druga boca u kadru kamere nije imala nikakvog utjecaja na mjerenje.
Naposljetku, navodimo tablicu (Tablica 2) materijala korištenih pri izradi laboratorijskog prototipa, pri čemu ne navodimo količinu za konstrukcijske/potporne materijale budući da oni neće biti potrebni (ne barem u tome obliku i obujmu na stvarnoj proizvodnoj liniji).

Tablica 2 – Najvažnije komponente korištene pri izradi Modula 1
Komponenta | Količina (jedinica)
OpenMV Cam H7 plus Image Sensor | 1 (kom)
AC 110-240V to DC 12V switching power supply converter SA10-05 | 1 (kom)
LM2596S DC-DC Constant Current Module Step-down Adjustable CC/CV Power Supply Module (kao opcija – kod rada sa RPi računalom; kamera je u laboratoriju napajana s USB kabelom i računalom) | 1 (kom)
IRONWALLS 2 Sets F-S2 Series 9005+9006 LED Headlight Bulbs (10W)⁸ s regulatorom napona / struje (na 12V) | 2 (kom)
IRFZ44N N-kanalni MOSFET | 1 (kom)
Prilagođena tiskana pločica | 1 (kom)
Potrošni materija (npr. aluminijski profili) | /

8
Npr. https://www.aliexpress.com/item/32909931750.html

19

## 3. MODUL ZA KONTROLU RAZINE TEKUĆINE NAKON PUNJENJA – Modul 2

Drugi princip rada koji je pokazao obećavajući rezultate, ali nešto lošije za sami proces punjenja (prvenstveno zbog mlaza tekućine koji se javlja kroz bocu tijekom samog procesa punjenja – Slika 18) se temeljio na svojstvu transmisivnosti (što uključuje i lom svjetlosti u fluidu) posude (boce) i fluida (tekućine u boci). Međutim ovakav sustav mjerenja je moguće relativno lako primijeniti nakon same punilice, kada boca prolazi pokretnom trakom (Slika 1). Ovaj pristup također polazi od pretpostavke da na boci (još uvijek) nema naljepnica koje bi ometale vidno bolje kamere.

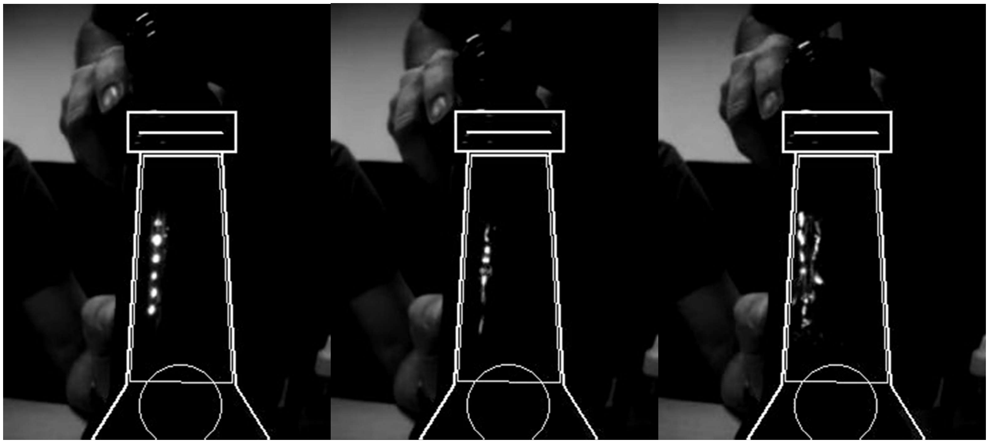
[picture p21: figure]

Slika 18 – Primjeri kada svjetlosni uzorak rastera se poklopi s mlazom tekućine koja puni bocu

Kako bi se sustavno testirao ovakav pristup konstruirano je nekoliko LED rastera različitih veličina i sa različitim izvorima svjetlosti. Primjer dva rastera se može vidjeti na Slici
18. Za detaljnija daljnja testiranja je odabran raster veličine 3x6 LED veličine 3 mm (lijevo na Slici 19). Ukoliko se boca nalazi između rasterskog izvora svjetlosti i kamere, svjetlosne zrake prolaze kroz bocu (prazni ili napunjenu fluidom) te dolaze do leće. Kamera drugačije vidi rasterski uzorak kada se u boci nalazi fluid, odnosno kada je boca prazna (Slika 20).

Slika 19 – Primjeri rastera upotrjebljenih prilikom testiranja

20

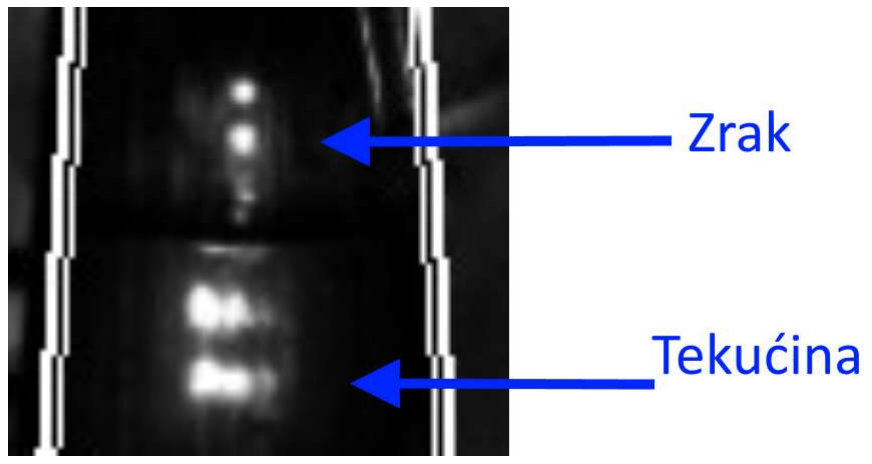
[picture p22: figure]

Slika 20 – Razlika uzorka svjetlosti koji prolazi kroz zrak i kroz fluid a kako ga vidi kamera (uvećani detalj)

Gore spomenuto svojstvo se može upotrijebiti kada je grlo boce (ili bilo koji drugi dio boce) napunjeno tekućinom, budući da se ona tada ponaša kao leća, odnosno drugačije lomi zrake upadne svijetlosti od iste boce kada se fluid ne nalazi u grlu. Primjer ispravnog funkcioniranja predložene ideje je vidljiv na Slici 21. Slika također ilustrira da se navedeni efekt može manifestirati na različite načine (pomakom i/ili izobličenjem izvora svjetlosti u slici kamere). Ovo je dodatni nedostatak ovoga pristupa koji uzrokuje potrebu implementacije nešto složenijeg programskog rješenja za klasifikaciju i mjerenje.

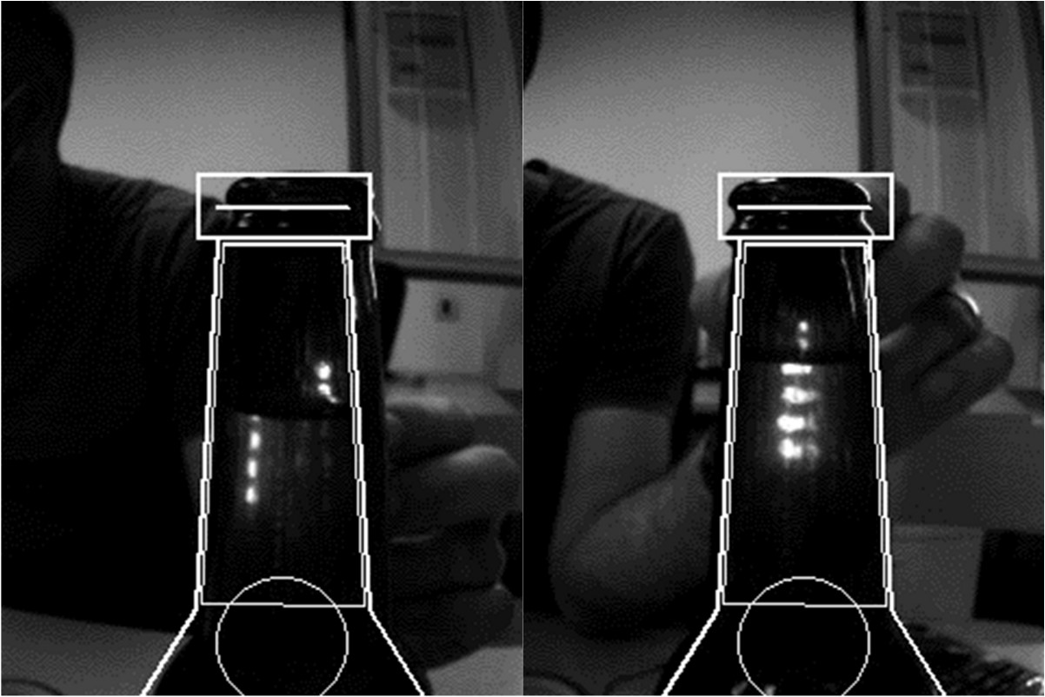
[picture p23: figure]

Slika 21 – Različite vizualni efekti kao posljedica svojstva tansmisivnosti

U slučaju idealnog poravnavanja kamere sa izvorom svjetlosti, nije primjetan lom svjetlosti, ali se može primijetiti drugačiji oblik izvora svjetlosti (3mm crvena LED), zbog efekta leće prilikom prolaska svjetlost kroz tekućinu. Slika 22 ilustrira primjer zamišljene implementacije senzora na proizvodnoj liniji kada boca prolazi između kamere i rasterskog izvora svjetlosti. Iz niza slika je vidljivo da se zbog različitih efekata transmisije koji se javljaju u procesu moguće odrediti liniju do koje je boca puna. Također slika pokazuje da u ovisnosti o trenutnom položaju boce ti efekti mogu biti drugačiji i za istu bocu.

21

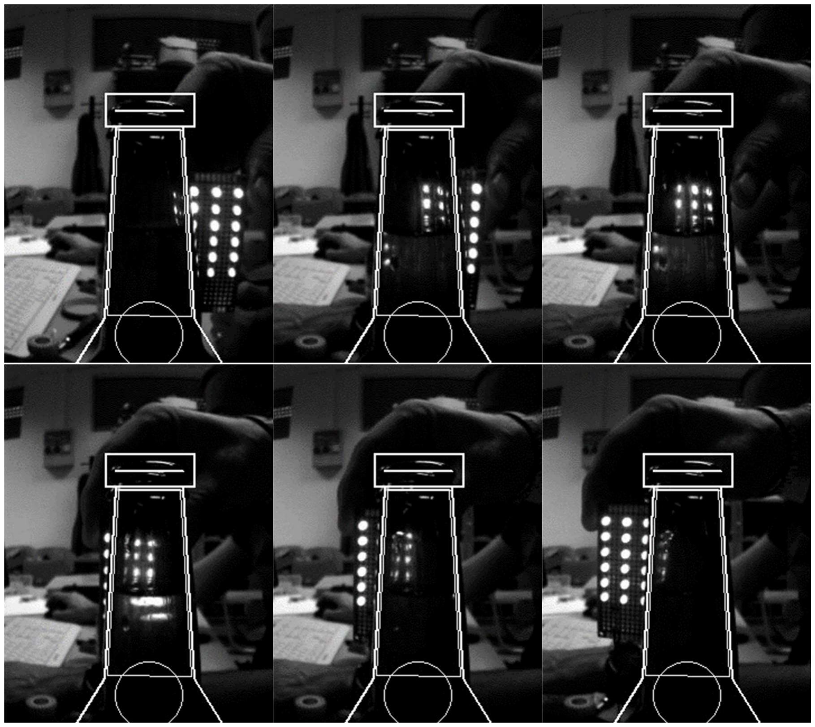
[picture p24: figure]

Slika 22 – Primjer mjerenja kada se boca kreće s lijeva na desno na pokretnoj traci

Naposljetku, kao i u prethodnom poglavlju, navodimo tablicu (Tablica 3) materijala korištenih pri izradi laboratorijskog testnog prototipa, pri čemu ne navodimo količinu za konstrukcijske/potporne materijale budući da oni neće biti potrebni (ne barem u tome obliku i obujmu na stvarnoj proizvodnoj liniji).

Tablica 3 – Najvažnije komponente korištene pri izradi modula za kontrolu razine
Komponenta | Količina (jedinica)
Žute LED 3 mm | 18 (kom)
DC-DC konverter s izlazom od 12V | 1 (kom)
USB kabel za napajanje | 1 (kom)
IRFZ44N N-kanalni MOSFET | 1 (kom)
Potrošni materija (tiskana pločica, aluminijski profili) | /

22

Napominjemo da se u razmatranim sustavima nije uklanjala distorzija leće kamere budući da su inicijalni testovi pokazali da to nije bilo potrebno (zbog konfiguracije sustava). Međutim dodatna poboljšanja bi bilo moguće dobiti ukoliko bi se izvršila kalibracija, pa postupak ovdje navodimo za slučaj da naručitelj želi isto implementirati u budućnosti. Kalibracija kamere se vrši kako bi se uklonila radijalna distorzija uzrokovana lećom kamere. Originalna slika sa kamere je prikazana na slici 23 lijevo, dok je ista slika nakon uklonjene distorzije prikazana na istoj slici desno. Zbog jako male fokalne duljine leće (2.8 mm leća sa M12 navojem) radijalna distorzija je u promatranom primjeru znatna (radi ilustracije).

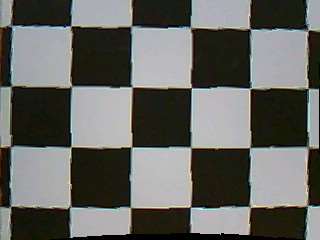
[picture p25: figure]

Slika 23 – Distorzirana slika sa kamere (lijevo), te slika nakon uklanjanja distorzije (desno)
U slučaju promjene leće kamere, korisnik se može poslužiti priloženim skriptom namjestanje_parametra_lece.py gdje se mogu izračunati parametri nove leće ili kamere. Važno je napomenuti da dvije iste kamere i leće nemaju iste parametre, i svaka promjena komponente sustava zahtjeva ponovno namještanje parametara leće (odnosno intrinzičnu kalibraciju). Računaju se parametri radijalne distorzije: središte distorzije (koje ne mora i niti je u sredini slike) i u konačnici ispravlja se nagib tj. rotacija kamere. Ista skripta se može koristiti i za (ekstrinzičnu) kalibraciju kamere, tj. povezivane piksela kamere (točke na slici kamere) i kuta od centralne osi kamere, pri čemu se izrađuje novi LUT. Alternativa je korištenje već u Python ugrađene naredbe koja pruža jednostavniji način kalibracije, ali nešto manje točan i sa manjom fleksibilnošću.
Spomenuti LUT-ovi se izrađuju pomoću skripte koja je kompatibilna sa MATLAB-om (ili Octave-om). U skriptama korisnik prati upute i unosi očitane koordinate za nekoliko točaka na temelju čega se interpoliraju vrijednosti za sve moguće vrijednosti na slici, i pripremaju u format zapisa Python dictionary-a. Takav kod (tekstualni) se kopira u zaglavlje Python skripte na za to predviđeno mjesto. Ovakav pristup omogućava krajnjem korisniku da po potrebi jednostavno izmjeni postavke rada sustava. Kao i kod primjera sustava za detekciju čepa boce, priloženi Python kod omogućava korisniku da jednostavno utječe na parametre rada sustava, bez potrebe za poznavanjem funkcionalnosti cijelog sustava.
Naposlijetku prikazujemo i dvije slike iz laboratorijskih testiranja sustava sa i bez Raspberry Pi 4B računala (Slika 24).

23

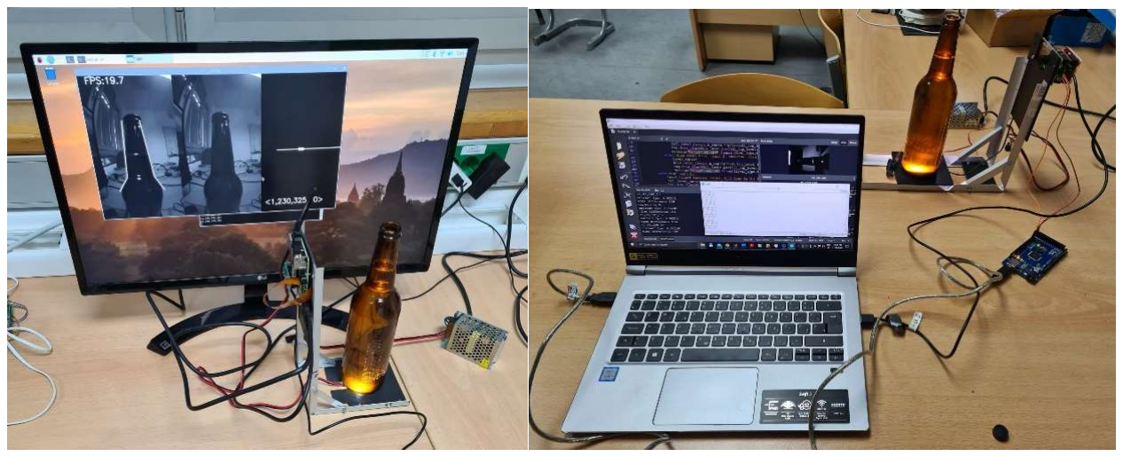
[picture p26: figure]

Slika 24 – Primjeri laboratorijskog testiranja dvije inačice sustava: sa RPi računalom (lijevo) i sa OpenMV H7 plus kamere.

24

## 4. STRUKTURA POPRATNOG CD-a SA PROGRAMSKIM DATOTEKAMA

Svi kodovi korišteni pri izradi oba modula su priloženi na CD-u koji je sastavni dio ove studije. Komentari koji se nalaze u odgovarajućim kodovima, zajedno s tekstom ove studije bi trebali biti dovoljni da bi svaki krajnji korisnik mogao shvatiti osnove funkcioniranja i karakteristike svakog modula, te promijeniti odgovarajuće parametre sustava u slučaju promjene neke od sklopovskih (ili drugih) komponenti sustava, a kako je to već na nekoliko mjesta istaknuto u studiji.
Radi lakšeg snalaženja na CD-u ovdje navodimo strukturu direktorija i to grafički slikom
25. Iz same strukture i naziva (pod) direktorija bi trebalo biti jasno što on sadrži.

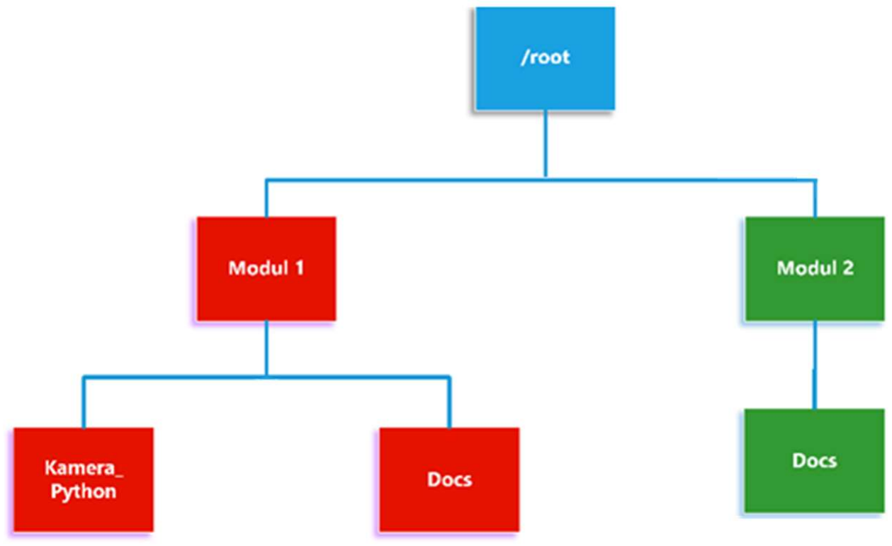
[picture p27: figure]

Slika 25 – Struktura direktorija na priloženom CD-u

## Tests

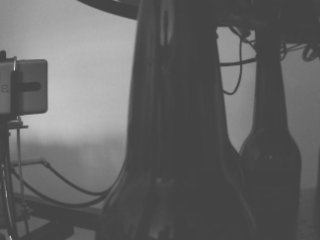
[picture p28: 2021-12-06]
modul 1 - openmv/Dokumentacija/test_slika_u_pivovari/slika_45_off.bmp

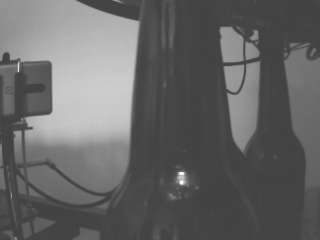
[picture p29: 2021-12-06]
modul 1 - openmv/Dokumentacija/test_slika_u_pivovari/slika_18_on.bmp

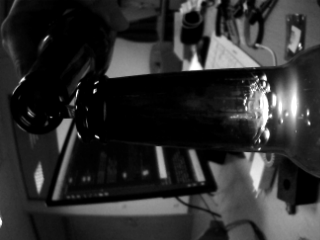
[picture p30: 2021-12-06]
modul 1 - openmv/Dokumentacija/test slike/slike diff 4 11 2021/slika_13_on.bmp

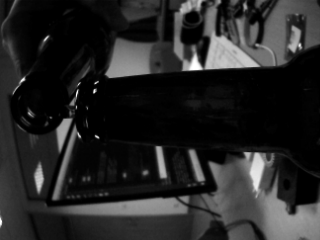
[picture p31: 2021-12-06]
modul 1 - openmv/Dokumentacija/test slike/slike diff 4 11 2021/slika_13_off.bmp

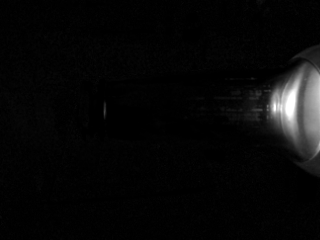
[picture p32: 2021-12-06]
modul 1 - openmv/Dokumentacija/test slike/slike diff 4 11 2021/diff_2.bmp

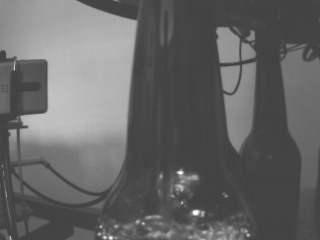
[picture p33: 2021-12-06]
modul 1 - openmv/Dokumentacija/test_slika_u_pivovari/slika_47_on.bmp

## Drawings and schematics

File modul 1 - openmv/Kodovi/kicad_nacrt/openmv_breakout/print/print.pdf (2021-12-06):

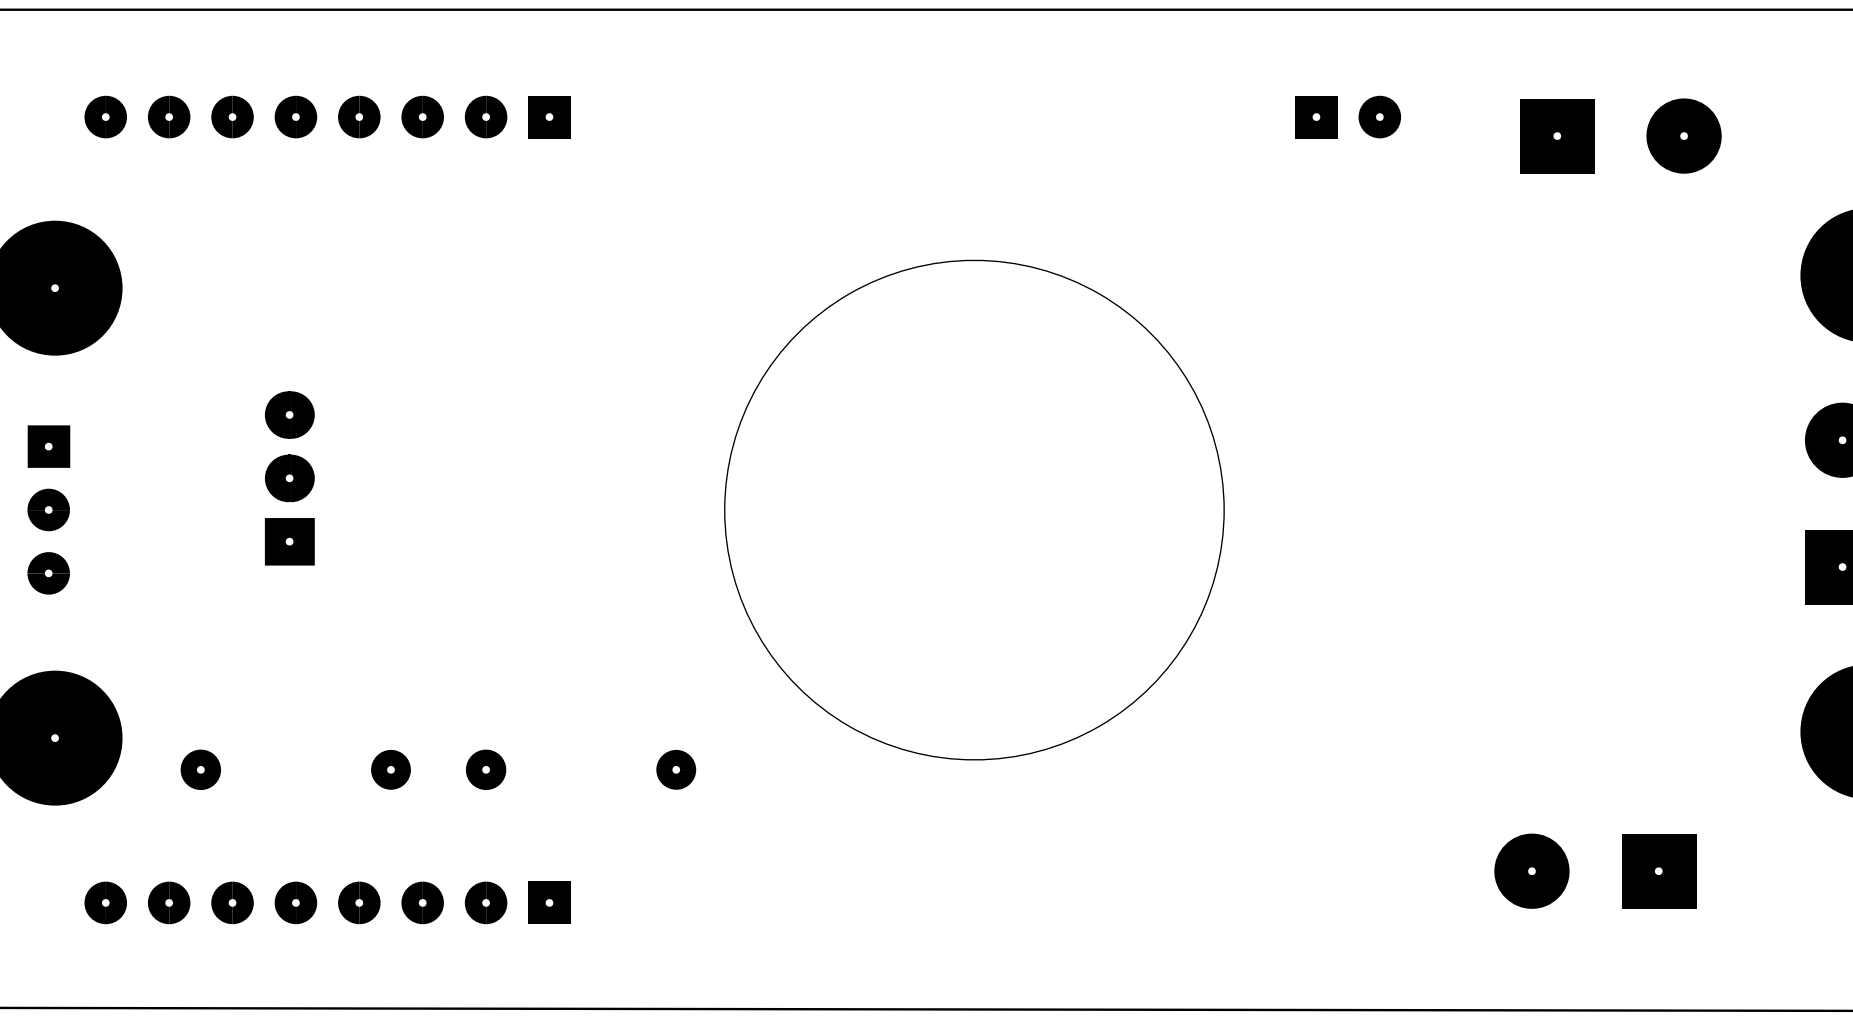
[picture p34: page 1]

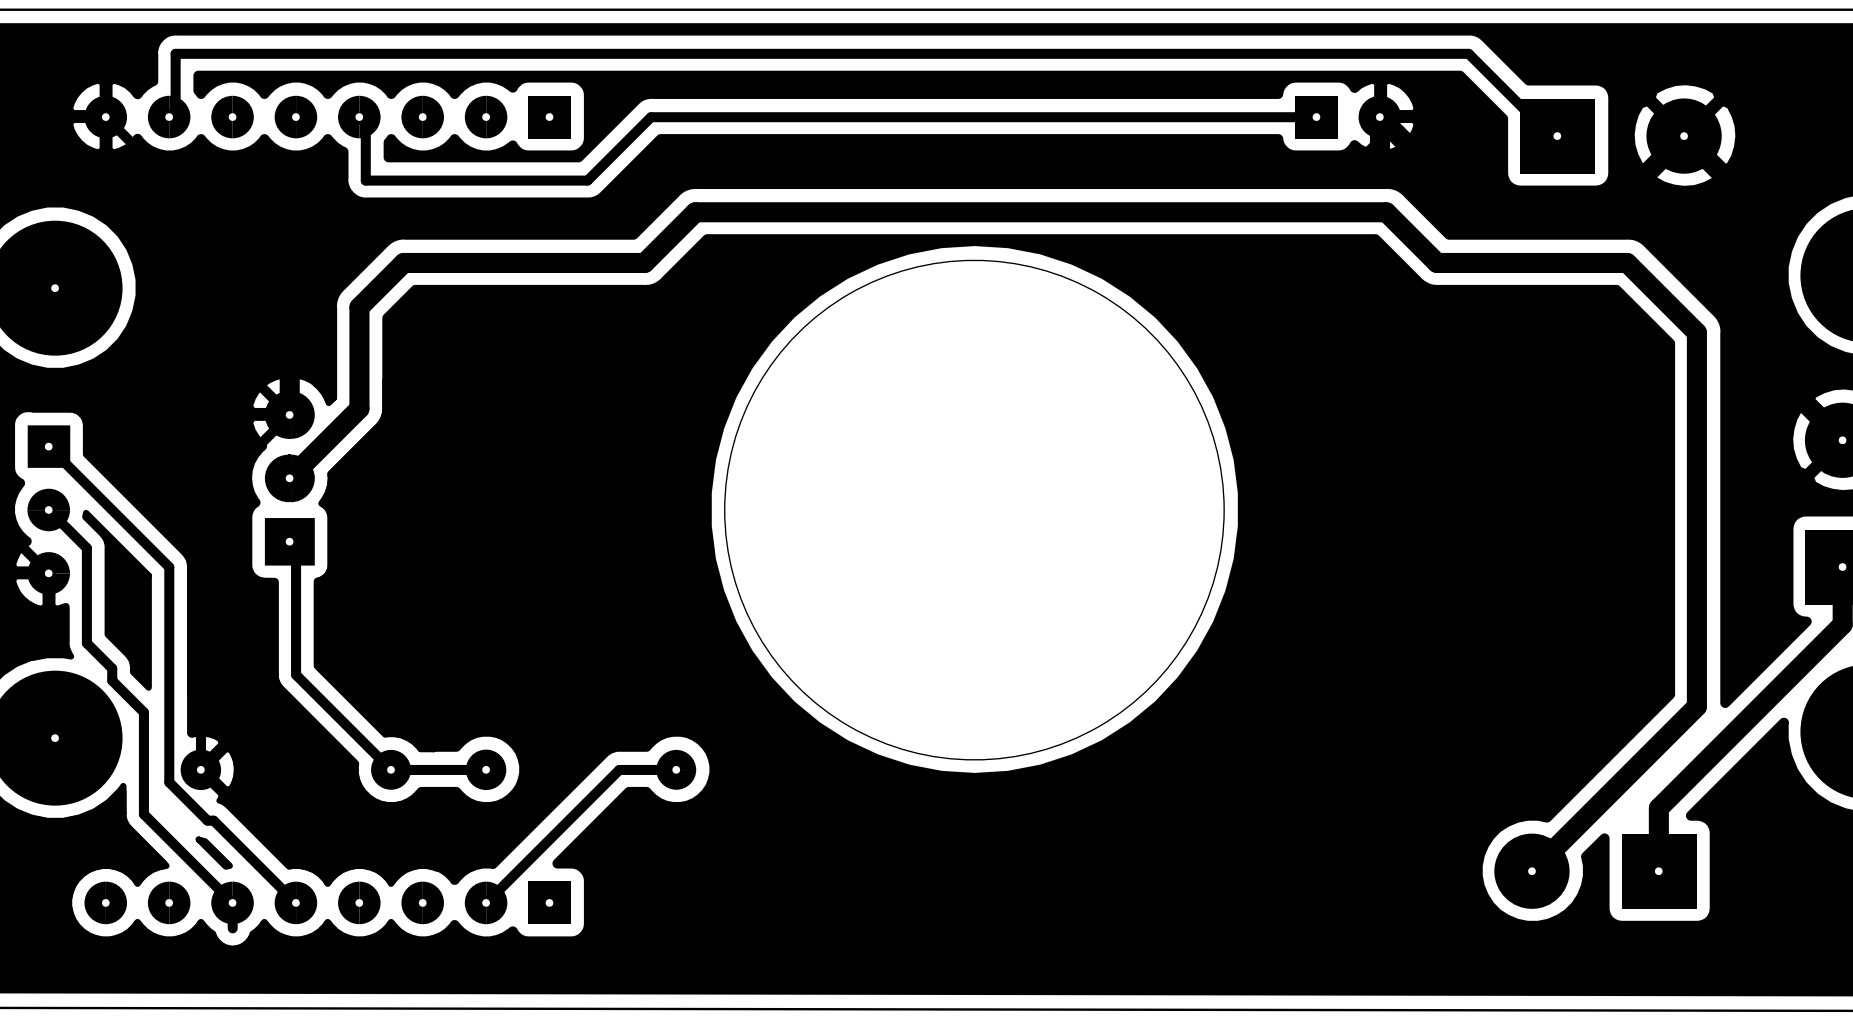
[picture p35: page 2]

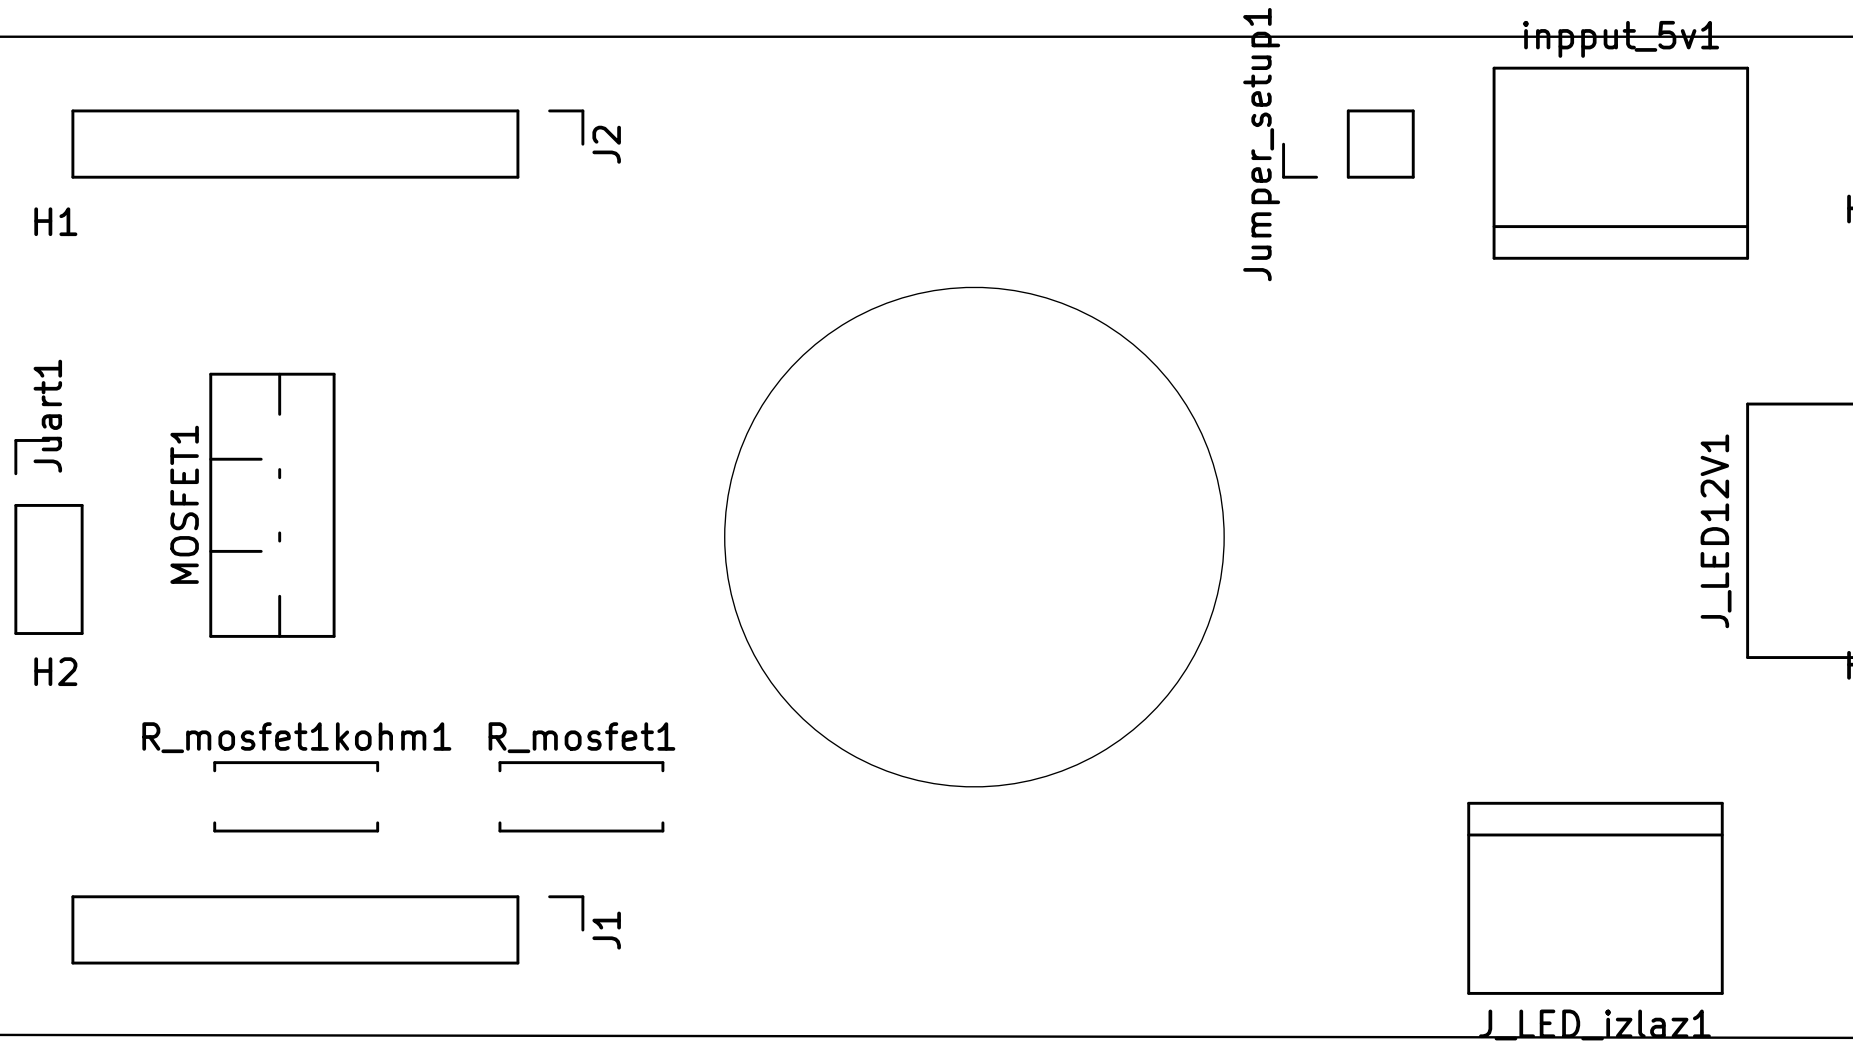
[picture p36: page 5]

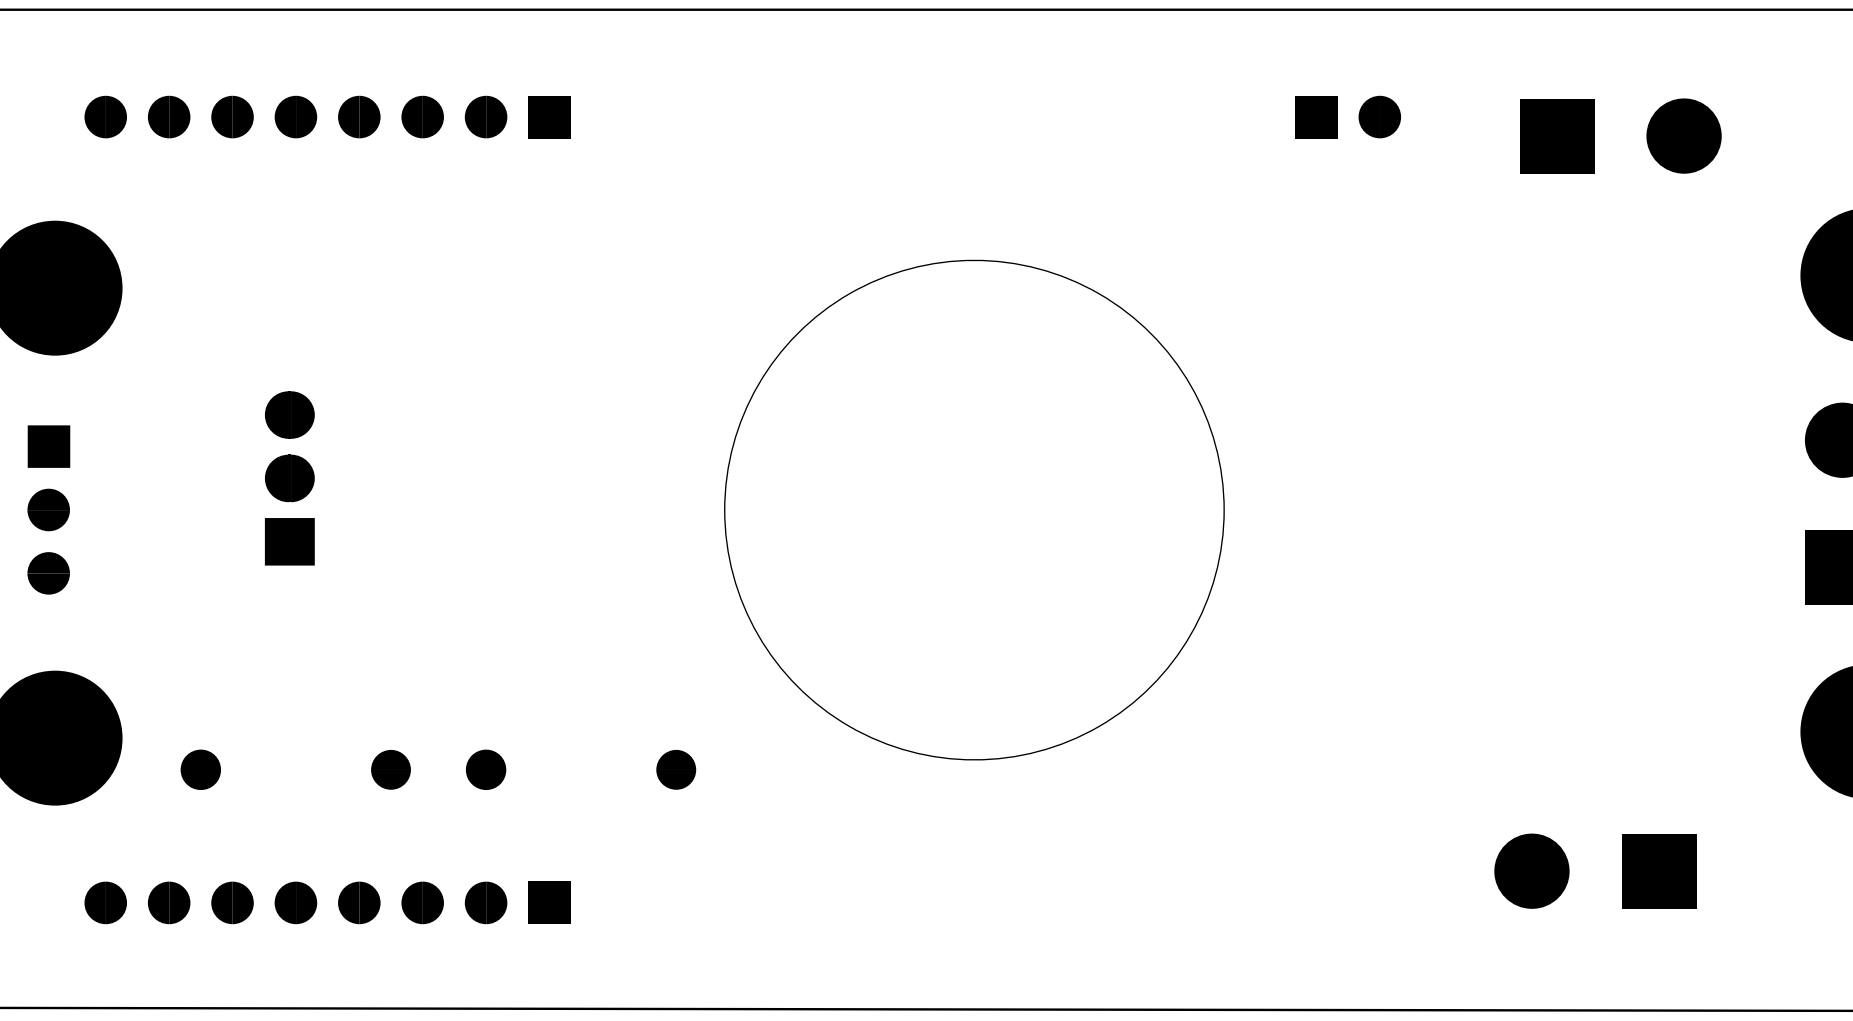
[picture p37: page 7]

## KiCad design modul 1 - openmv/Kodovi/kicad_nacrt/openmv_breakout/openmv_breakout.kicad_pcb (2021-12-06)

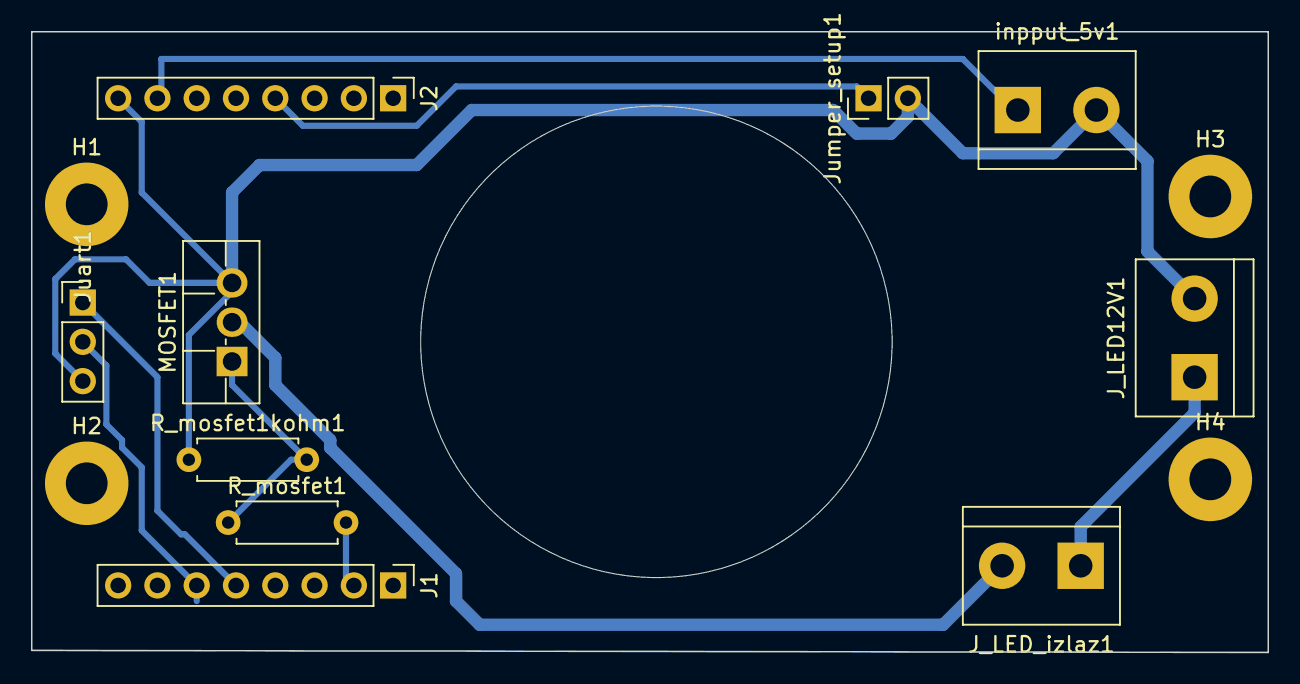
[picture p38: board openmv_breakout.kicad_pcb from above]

Board: 2 copper layers, 79.9 x 40.1 mm, 14 parts (0 on the bottom side), 9 nets.

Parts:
H1, H2, H3, H4: MountingHole; MountingHole_2.7mm_Pad
J1, J2: Conn_01x08_Male; PinHeader_1x08_P2.54mm_Vertical
J_LED12V1: Conn_01x02_Female; TerminalBlock_bornier-2_P5.08mm
J_LED_izlaz1: Conn_01x02_Female; TerminalBlock_bornier-2_P5.08mm
Juart1: Conn_01x03_Female; PinHeader_1x03_P2.54mm_Vertical
Jumper_setup1: Conn_01x02_Male; PinHeader_1x02_P2.54mm_Vertical
MOSFET1: IRLIZ44N; TO-220F-3_Vertical
R_mosfet1, R_mosfet1kohm1: R; R_Axial_DIN0207_L6.3mm_D2.5mm_P7.62mm_Horizontal
inpput_5v1: Conn_01x02_Female; TerminalBlock_bornier-2_P5.08mm

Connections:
5vin: J2.7, inpput_5v1.1
12V+: J_LED12V1.1, J_LED_izlaz1.1
DRAIN: J_LED_izlaz1.2, MOSFET1.2
GATE: MOSFET1.1, R_mosfet1.1, R_mosfet1kohm1.2
GND: J2.8, J_LED12V1.2, Juart1.3, Jumper_setup1.2, MOSFET1.3, R_mosfet1kohm1.1, inpput_5v1.2
P4: J1.2, R_mosfet1.2
P9: J2.4, Jumper_setup1.1
rx: J1.6, Juart1.2
tx: J1.5, Juart1.1

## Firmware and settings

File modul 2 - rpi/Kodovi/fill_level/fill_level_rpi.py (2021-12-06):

#*****************************************
# Fluid fill level sensor, based on machine vision
# This verion uses RPi4B + CAM + 20W LED
# Created by FESB CV team || 11. 2021.
# istancic@fesb.hr jmusic@fesb.hr
# Project Opinau-Filler-CV-2
#*****************************************

#basic definitons, iports, etc.

#some imports libraries etc.
import arducam_mipicamera as arducam
import v4l2 #sudo pip install v4l2, camera driver
import time
import cv2 #sudo apt-get install python-opencv
import numpy as np;
from gpiozero import LED

#output pin to LED
red = LED(17)

# identity kernel  for filtering, for vertical camera installation
kernel1 = np.array([[1, 0, -1],
                    [1, 0, -1],
                    [1, 0, -1]])
#kernel for dilatation
kernel = np.ones((3,3),np.uint8)

#definition of top fill level in pixels - please change!
fill_top_level=100

#mv system starts in measurement mode. 
#changes via keypress
#s - start measurement and report
#t - terminate measurement and reporting
measurement_mode=True

#mask definitions, only part of image under mask is considered
#mask is prepared as bmp image 
maska=cv2.imread('maska_rpi.bmp', cv2.IMREAD_GRAYSCALE)
_, maska = cv2.threshold(maska, 64, 255, cv2.THRESH_BINARY)

#commands for basic camera operations
def align_down(size, align):
    return (size & ~((align)-1))

def align_up(size, align):
    return align_down(size + align - 1, align)

def set_controls(camera):
    try:
        print("Reset the focus...")
        camera.reset_control(V4L2_AUTO_FOCUS_RANGE_MACRO)
        camera.set_control(V4L2_CID_EXPOSURE_ABSOLUTE, 100)
    except Exception as e:
        print(e)
        print("The camera may not support this control.")

    try:
        print("Enable Auto Exposure...")
        #camera.software_auto_exposure(enable = True)
        print("Enable Auto White Balance...")
        camera.software_auto_white_balance(enable = False)
    except Exception as e:
        print(e)
#end of commands for basic camera operations

#main loop
if __name__ == "__main__":
    try:
        camera = arducam.mipi_camera()
        print("Open camera...")
        camera.init_camera() #starting the camera
        print("Setting the resolution...")
        fmt = camera.set_resolution(640,480) #low resolution for faster operation
        print("Current resolution is {}".format(fmt))
        set_controls(camera)
		
        while True: #loop until q key is presses
            
            
            start=time.time() #record current time, for FPS calculation
            
            keypress=cv2.waitKey(1)    #wait for input key
            if keypress & 0xFF == ord('s'): #start measurement mode
                    measurement_mode=True
            elif keypress & 0xFF == ord('t'): #terminate measurement mode
                    measurement_mode=False
            elif keypress & 0xFF == ord('q'): #quit main loop
                    break
                    
            if measurement_mode==True: #execute if set to measurement mode    
                
                red.on() #turn on LED
                time.sleep(0.005) #wait for 50ms 
                frame1 = camera.capture(encoding = 'i420') #capture  firstimage
                time.sleep(0.002) #wait for 2ms 
                red.off() #turn off LED
                time.sleep(0.012) #wait for 12ms 
                frame2 = camera.capture(encoding = 'i420') #capture second image
                
                image1 = frame1.as_array.reshape(600, 640) #decode fist image
                image1 = cv2.cvtColor(image1, cv2.COLOR_YUV2GRAY_I420) #convert to grayscale
                
                image2 = frame2.as_array.reshape(600, 640) #decode second image
                image2 = cv2.cvtColor(image2, cv2.COLOR_YUV2GRAY_I420) #convert to grayscale
                
                image=cv2.absdiff(image1,image2) #absoule diff of both images
                
                image= cv2.filter2D(src=image, ddepth=-1, kernel=kernel1) #kernel filtering, keep only verical lines (camera is roatated)
                _, image = cv2.threshold(image, 64, 255, cv2.THRESH_BINARY) #create binary image
                
                image=cv2.bitwise_and(image, maska) #mask operation, keep only are under mask

                image = cv2.dilate(image,kernel,iterations = 2) #dilatation, to connect if blob is separated on several close blobs
                image = cv2.morphologyEx(image, cv2.MORPH_CLOSE, kernel) #close some holes in blob

                contours, hierarchy = cv2.findContours(image, cv2.RETR_TREE, cv2.CHAIN_APPROX_SIMPLE) #find contours in binaryimage
                
                x_max,h_max,w_max,cont_area=320,0,0,0  #to keep location and info for largest blob/ contour
                
                x_top,w_top=320,0 #to keep location and info for topmost blob
                contours_counter=0  #contours counter
                for c in contours: #for loop, check all contours

                    message="" #message placeholder, 

                    if cv2.contourArea(c)>80: #check only contours larger than 80 pix
                        contours_counter+=1 #increment contours by one
                        x,y,w,h = cv2.boundingRect(c) #extract contour size info
                        if cv2.contourArea(c)>cont_area: #if area of courrently largest
                            x_max=x  #record cuurently largest contour info
                            w_max=w
                            h_max=h
							
                        if x<x_top: #if current contour is topomost (closest to bottle throat)
                            x_top=x #record cuurently topmost contour info
                            w_top=w
                        
						#drav rectange on image around contours
                        image = cv2.rectangle(image,(x,y),(x+w,y+h),(255,0,0,),2)
                
                #preparing message  -> to ROS or other
				#currently message is printed to serial console
				
                if contours_counter==1: #if number of conturs is one!
                    if h_max/w_max>1.5: #single elongated blob, class 1, no foam. steady fluid
                        fill_level_px=x_max+int(w_max/2)-fill_top_level
                        message="<{},{},{},{}>".format(1,fill_level_px,x_max,w_max)
                        image = cv2.line(image,(x_max+int(w_max/2),1),(x_max+int(w_max/2),320),(255,255,0,),2)
                    else: #one large blob, class 2, excesive  foam 
                        fill_level_px=(x_max+3)-fill_top_level
                        message="<{},{},{},{}>".format(2,fill_level_px,x_max,w_max)
                        image = cv2.line(image,(x_max+3,1),(x_max+3,320),(255,255,0,),2)
                elif contours_counter>1: #several blobs, fill line is the topmost blob - 3px due to dilatation
                    fill_level_px=(x_top-3)-fill_top_level
                    message="<{},{},{},{}>".format(3,fill_level_px,x_top,w_top)
                    image = cv2.line(image,(x_top+3,1),(x_top+3,320),(255,255,0,),2)
                else: #no blobs detected, all zeros printed / sent to USART
                    message="<{},{},{},{}>".format(0,0,0,0)

                print(message) #printig current message
                
				#adding line for bottle alignment , fist image
				#user may change line location according to bottle type
				#in that scenario, mask should also be changed
                image1 = cv2.line(image1,(180,160),(435,125),(255,255,0,),2)
                image1 = cv2.line(image1,(435,125),(500,84),(255,255,0,),2)
                image1 = cv2.line(image1,(180,240),(435,255),(255,255,0,),2)
                image1 = cv2.line(image1,(435,255),(500,300),(255,255,0,),2)

                #rotate image 90 deg (camera is installed vertically)
                image1=cv2.transpose(image1)
                image1=cv2.flip(image1,flipCode=1)
                #rotate image 90 deg (camera is installed vertically)
                image2=cv2.transpose(image2)
                image2=cv2.flip(image2,flipCode=1)
                #rotate image 90 deg (camera is installed vertically)
                image=cv2.transpose(image)
                image=cv2.flip(image,flipCode=1)
                #concatenate all three images in one
                image=np.concatenate((image1, image2,image), axis=1)
                
                #calculate current FPS
                fps=1/(time.time()-start)
                fps_str="FPS:{0:.1f}".format(fps) #prepare string message
                image = cv2.putText(image, fps_str, (30,30), cv2.FONT_HERSHEY_SIMPLEX, 1.2, (255,0,0), 2, cv2.LINE_AA) #print current FPS on image
                
                image = cv2.putText(image, message, (820,600), cv2.FONT_HERSHEY_SIMPLEX, 1.2, (255,0,0), 2, cv2.LINE_AA) #print current message to last image
                #image=cv2.resize(image, (800,480), interpolation = cv2.INTER_AREA) #resize for small LCD screen

                cv2.imshow("Filler", image) #show image

            else: #if not in measurement mode
                frame1 = camera.capture(encoding = 'i420') #capture  firstimage
                image1 = frame1.as_array.reshape(600, 640) #decode fist image
                image1 = cv2.cvtColor(image1, cv2.COLOR_YUV2GRAY_I420) #convert to grayscale
				#rotate image 90 deg (camera is installed vertically)
                image1=cv2.transpose(image1)
                image1=cv2.flip(image1,flipCode=1)
				#concatenate two same images into one, no reason :)
                image1=np.concatenate((image1, image1), axis=1)
				#resize for small LCD screen
                #image1=cv2.resize(image1, (800,480), interpolation = cv2.INTER_AREA)
                cv2.imshow("Filler", image1) #show image
            


        # Release memory
        del frame1
        del frame2
        print("Close camera...")
        cv2.imwrite("last_frame.jpg",image) #record last image into jpg file
        camera.close_camera() #close camera
        cv2.destroyAllWindows() #close all windows
		
    except Exception as e: #print if some exceptation occurs
        print(e)

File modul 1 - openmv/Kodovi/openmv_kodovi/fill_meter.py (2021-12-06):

#*****************************************
# Fluid fill level sensor, based on machine vision
# Project uses OpenCV H7plus camera + 20W LED
# Created by FESB CV team || 11. 2021.
# istancic@fesb.hr jmusic@fesb.hr
# Project Opinau-Filler-CV-2
#*****************************************

#basic definitons, iports, etc.

#some imports libraries etc.
import sensor, image, time, lcd #basic libraries
from pyb import Pin #use hardware inputs / outputs
from pyb import LED #use bult-in LED
from pyb import UART  #enables use of hardware serial (UART)


#Built in LED definitions, used for fill status indication
red_led   = LED(1) # red led- fluid >500ml
green_led = LED(2) # green led - fluid detected, <500 ml
blue_led  = LED(3) # blue led - no fluid detected


#output pin, no pullup
#pin_LED = Pin('P1', Pin.OUT_PP, Pin.PULL_NONE) #output, to LED  (MOSFET)

uart = UART(3, 115200)  #UART pin 4, 9600 baudrate
#uart.init(9600, bits=8, parity=None, stop=1, timeout_char=1000)


#iput pin,pullup (button or jumper can be connected between pin and GND line)
#setup jumper, connect if allignmet of camera is required (enters setup mode)
pin_setup = Pin('P9', Pin.IN, Pin.PULL_UP) #input - setup jumper


# camera expostion time in ms. keep it between 4000 and 10000 interval
user_exposure_time=4000 #change if bottle type and/or color is changed


#use debug mode for forcing output to IDE, additional delay 500ms per measerement
#debug_mode=True
debug_mode=False

#mv system starts in measurement mode. changes via USART commands
measurement_mode=True


#fill level definitions, user chan change this
fill_top_level=100 #define line which represenst top of the bottle (throat begining)

#please adjust this option to different bottle type
fill_level_px_limit=90 # defines diff in pixels between fill_top_level and current fill level line

#minimal size og blod - detected line, 20 is the default option
min_blob_size=20

#camera sensor setup
sensor.reset() # Initialize the camera sensor
sensor.set_pixformat(sensor.GRAYSCALE) # set camera format to grayscale (color not important in this example)
sensor.set_framesize(sensor.QVGA) # set camera resolution to QVGA 320 x 240
sensor.set_auto_exposure(False, exposure_us=user_exposure_time) # set exposure time, user changable (user_exposure_time variable)
sensor.set_auto_gain(False,gain_db=22) #set camera gain, keep it as this value is optimised for given light source and exposure time
sensor.set_brightness(3) #set camera brightness , range -3 to +3
sensor.set_contrast(3) #set camera contrast , range -3 to +3

#important command! forces camere not to store frames!!
sensor.set_framebuffers(1) #only single frame in buffer!
sensor.skip_frames(time = 2000) #alow some time for camera to initialise
#camera setup is finished


#additional frame buffers
extra_fb = sensor.alloc_extra_fb(320,240, sensor.GRAYSCALE) #for frame diferencing
extra_fb2 = sensor.alloc_extra_fb(120,160, sensor.RGB565) #not used ...
mask = sensor.alloc_extra_fb(320,240, sensor.GRAYSCALE) #mask definition

lcd.init(type=lcd.LCD_SHIELD) # Initialize the lcd screen.


#kernel definitions, object filtering by orientation
kernel_size = 1 # 3x3==1, 5x5==2, 7x7==3, etc. our kernel is size 3x3

#kernel for horizontal camera instalaltion
#kernel = [2, 2,  2, \
          #0, 0,  0, \
           #-1,  -1,  -1]

#kernel for vertical camera installation
kernel = [2, 0,  -1, \
          2, 0,  -1, \
           2,  0,  -1]
#kernel definiton is finished

#threshold defininitions for binarisation. please change lower number if required (20 default)
low_threshold=(20, 255)

#mask definitions, only part of image under mask is considered
#mask is defined by series of simple objects(lines), than area defined by lines is filled
mask.clear() #clear mask, add some lines

mask.draw_line(102, 107, 250,92, color = (255, 255, 255), thickness = 1)
mask.draw_line(250, 92,250,166, color = (255, 255, 255), thickness = 1)

mask.draw_line(250,166, 102, 152, color = (255, 255, 255), thickness = 1)
mask.draw_line(102, 152,102,107, color = (255, 255, 255), thickness = 2)

#mask.draw_circle(260,130,25,color = (255, 255, 255), thickness = 1, fill = False)

mask.flood_fill(190, 120, seed_threshold=0.05, floating_thresholds=0.05,color=(255, 255, 255), invert=False, clear_background=False)
mask.draw_circle(260,130,25,color = (255, 255, 255), thickness = 1, fill = False)
#maska.draw_circle(290,110,25,color = (0, 0, 0), thickness = 1, fill = True)

mask.binary([(20, 255)]) #bynarise mask,
mask.erode(3) #erode mask, small movement or vibrations of bottle can detect false fill level on bottle edges
#eroding the mask can help prevent this
#mask definition is compleete


#setup mode, run if setup jumper is set!
#this allows user to correcty alling bottle
while(pin_setup.value()==False):  #execute while jumper is set
    img = sensor.snapshot() #take single image

    #draw alignmenet lines
    img.draw_rectangle(70, 100, 30, 60, color = (255, 255, 255), thickness = 2, fill = False)
    img.draw_line(85, 110, 85, 150, color = (255, 255, 255), thickness = 2)


    img.draw_line(100, 105, 250, 90, color = (255, 255, 255), thickness = 2)
    img.draw_line(250, 90,300,60, color = (255, 255, 255), thickness = 2)
    img.draw_line(300, 60,320,55, color = (255, 255, 255), thickness = 2)

    img.draw_line(100,155, 250, 170, color = (255, 255, 255), thickness = 2)
    img.draw_line(250, 170,300,200, color = (255, 255, 255), thickness = 2)
    img.draw_line(300, 200,320,205, color = (255, 255, 255), thickness = 2)

    #show image to LCD
    lcd.display(img,x_size=128,y_size=160) # Take a picture and display the image.
    print(img.compress_for_ide(), end="") #force image to IDE
    time.sleep_ms(100) #small delay, fps is reducet to 5
#setup mode is finished
lcd.set_backlight(0)
lcd.clear()
lcd.deinit()
#output pin, no pullup
pin_LED = Pin('P1', Pin.OUT_PP, Pin.PULL_NONE) #output, to LED  (MOSFET)

clock = time.clock()   # Create a clock object to track the FPS.

counter=0 #simple counter

#here goes the main code!
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
